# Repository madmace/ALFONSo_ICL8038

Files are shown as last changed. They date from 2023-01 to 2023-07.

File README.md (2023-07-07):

# A.L.F.O.N.S.o based on ICL8038

ALFONSo stands for :

<p align="right">
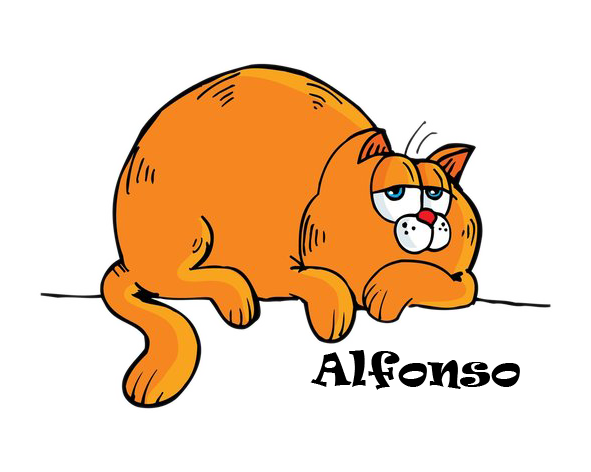
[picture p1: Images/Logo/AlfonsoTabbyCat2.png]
    
</p>

**A**nalog
**L**ow 
**F**requency 
**O**scillator 
**N**olinear 
**S**equencer

In this implementation MK-ICL8038.

- [Meta](#meta)
- [Basics](Basics.md)
- [Power Supply](Power.md)
- [ICs used in VCO & Mixer](ICs.md)
- [Frequency Counter](Frequency.md)
- [Early implementation](#early-implementation)
- [Development pictures](Images.md)
- [Current wiring diagram](https://github.com/madmace/ALFONSo_ICL8038/blob/main/Proteus/Alfonso_ICL8038.PDF)
- [Upcoming implementations](#upcoming-implementations)

## Meta

Scope:

- The project from my passion of analog synthesizers and the love of the patterns, rhythms and mats that colored the majority of the 70s and 80s classics. In particular the analog sequencers and LFOs.
- The use of analog IC monolith signal generators operated in BF in the 1Hz band up to 25KHz. Can be used as VCO/LFO. This first research *intentionally* uses the older, now obsolete, but *well known* **Intersil ICL8038**.
- The digital control interface via USB is based on an *old and well-known* Microchip **18-series** microcontroller. The **PIC18F4550** is a widely used mC and there is a large amount of example code and tutorials available on the web.
  However, I personally always suggest having its datasheet handy and dedicating the time to understand its correct functioning.
- Alfonso uses the USB 2.0 peripheral contained in the 18F4550 microcontroller. The firmware exposes the USB port as a CDC (USB communications device class). This allows it to be recognized by all OSes as an RS232 serial port.
  I originally intended to use the USB port as a Human Interface Device (HID) but due to its limitations I decided to implement it as a CDC and build a proprietary protocol on it.

## Early implementation

This first implementation is oriented to develop and test all the HW functionalities of the VCOs/LFOs and the core SW libraries for their command.
For this, a first mixer with the basic functions was developed.

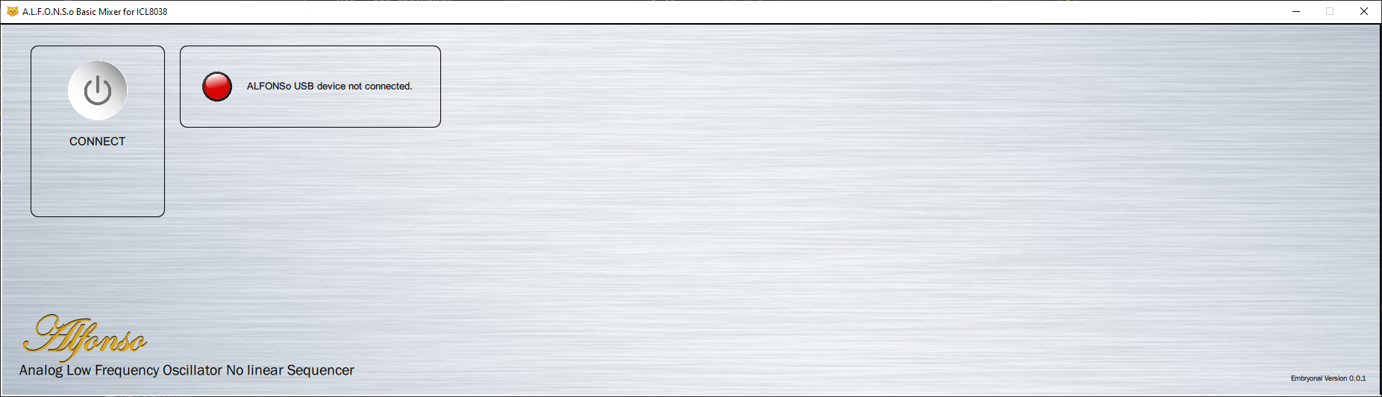
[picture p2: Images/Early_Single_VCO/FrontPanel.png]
Front Panel

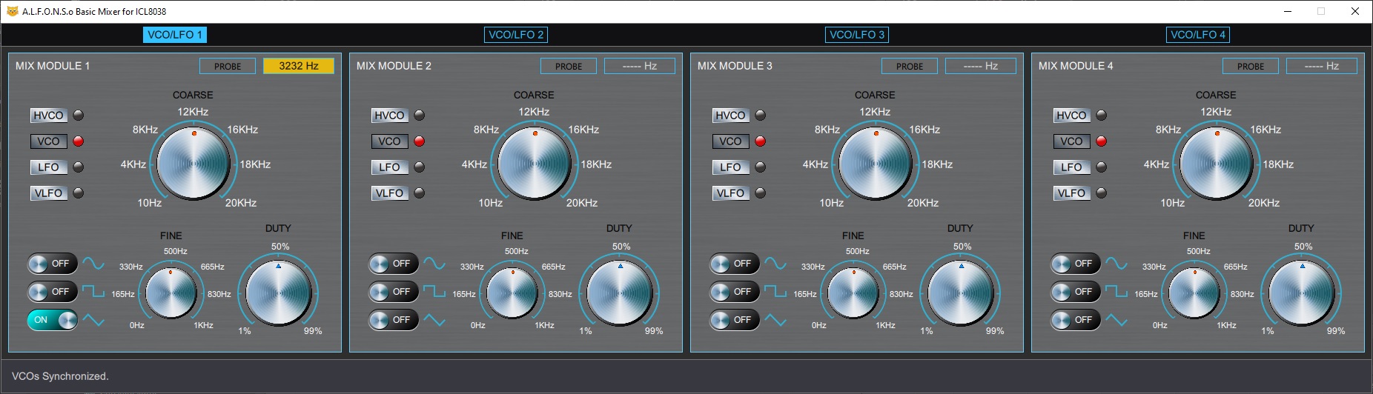
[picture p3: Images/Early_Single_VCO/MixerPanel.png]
Mixer Panel


Both the control logic section and the analog section with the VCO and the mixers are still being prototyped via breadboard.
Once the functionality is stabilized, I will create a welded version for better signal quality. Obviously the air links are not optimal.
    
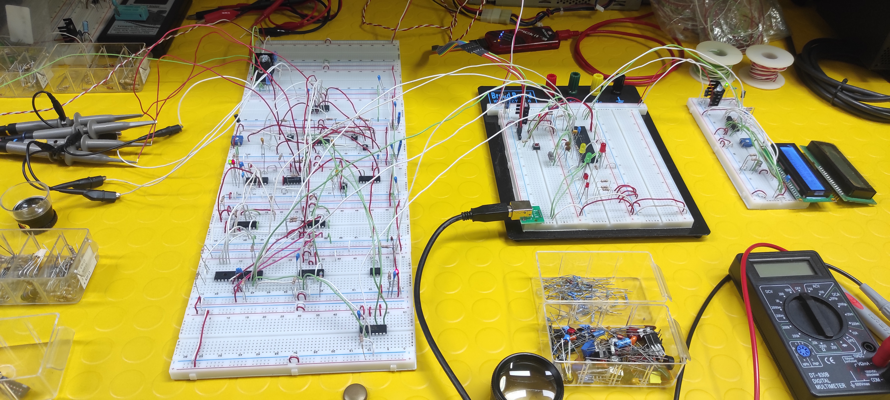
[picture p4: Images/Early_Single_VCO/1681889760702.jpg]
AlfonsoProto


## Upcoming implementations

- It is my intention, once the project based on the **Intersil ICL8038** is completed and stabilized, to re-adapt it for use with the **EXAR XR-2206** Monolithic Function Generator.
  IC is more modern and seems to compensate for certain problems of the *ICL8038*. It is also still supported and in production.
- The impact on the Firmware of the transition of the current mC **PIC18F4450** towards the new version, currently supported by the *MCC of MPLABX*, mC **PIC18F45K50** is minimal.
  So as soon as the current version stabilizes, I'll switch to this mC.

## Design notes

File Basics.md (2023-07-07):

---
title: Basics
layout: template
filename: Basics.md
--- 

## Basics

The **ICL8038** waveform generator is a monolithic integrated circuit capable of producing high accuracy sine, square, triangular, sawtooth and pulse waveforms.
The frequency (or repetition rate) can be selected externally from 0.001Hz to more than 300kHz.
In used configuration, the frequency has been fixed in the audio frequency range 1Hz to 20KHz.
As a quick description of how waveforms are produced, the integrators via comparators create the primary triangle which is then flip-flopped to obtain the square and a smoothing network based on multiple transistors stages to obtain the sine.
The sweep is modulated via a DC voltage. The relative frequency range depends on the capacitor applied.

Four different meshes with different values are needed to get good linearity.
This especially applies to operation as an LFO.
Four different selectable operating modes have been selected.

***Frequency ranges***

The frequency ranges are still raw and are related to the values of the capacitors used in the VCO applied to pin 10 of the ICL8038.

- **HVCO** (*1.6KHz to 26KHz used capacity 2.2uF*)
- **VCO** (*238Hz to 4.1KHz used capacity 220nF*)
- **LFO** (*11Hz to 194Hz used capacity 22nF*)
- **VLFO** (*3Hz to 67Hz used capacity 2nF*)

The selection of the frequency range is set using the micro via the I/O Expander **MCP23S17** and the Quad Bilateral Switch **CD4066B**.
Only one of the four bilateral switches is active defining the frequency range.

***Notice !***
The capacitor values and frequency range are still being refined, so the correct values will only be released upon completion of the design of the VCOs module.

[Return to index.](README.md)

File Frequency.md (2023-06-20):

## Frequency Counter

The purpose of this module is to communicate the current frequencies of the VCOs to the PC.

***Implementation via CCP module (Capture / Compare/ PWM) as "Initial choice"***

My intention was to use the Capture mode of the two available CCPs,
in particular the CCP2 combined with the Timer3 to calculate the frequency of the 5V/0 square conditioned signal made compatible with the digital input.

I didn't want to use other external components, thus subtracting other GPIOs from the uC.<BR>
My choice was to directly use the FOsc of 48Mhz / TOsc of 12Mhz on the Timer3.

The four operating ranges of the VCOs would have been managed with different samplings of the CCP.

- **HVCO** Capture mode: every 16th rising edge
- **VCO** Capture mode: every 4th rising edge
- **LFO** Capture mode: every rising edge
- **VLFO** Capture mode: every rising edge

With the 16-bit Timer3 and associated to the uC clock oscillator :

12Mhz/64K = 183 Timer3 Overflows per second.
With : 1/183 = 5.4644~ ms for each Overflow.

In the case of management with a single Overflow, this is the maximum time available to the CCP2.<BR>
So the minimum frequencies with respect to the three sampling ratios :

- 1:1 every rising edge 183 Hz
- 1:4 every 4th rising edge 732 Hz
- 1:16 every 16th rising edge 2.928 KHz

In VLFO mode the minimum frequency is ~3Hz, so we're not there.

The problem is Timer3 is the reference frequency which is very high.

***Reference 16bit Timer with managed Overflows***

To solve the problem I thought if it was possible to use a management with the managed Overflow of the same Timer3.

- With double Overflow management, the maximum period would be : 10.9289 ms for a minimum frequency of 91.5 Hz
- With triple Overflow management, the maximum period would be : 16.3932 ms for a minimum frequency of 61 Hz
- With a management of ten Overflows the maximum period would be : 54.644 ms for a minimum frequency of 18.3 Hz

This added to the fact that the Timer3 has the possibility to be managed via Prescaler 1:2, 1:4, 1:8 I could have achieved the goal,
but at the cost of a high computational complexity in the uC and a high imprecision given by the decimals.

So I decided to abandon the solution via CCP.

***Timer1 with external quartz 32.768KHz as RTC***

The Timer1 of the micro has the possibility of advancing with the system clock but also with an external quartz.
In this case I used the classic 32.768Khz RTC quartz. This technique is extensively described in the PIC18F4550 datasheet on page 131, paragraph 12.3.

By setting the Timer1 register with an initial prescaler of 0x8000 (32768) we obtain that each Timer1 overflow corresponds exactly to one second.
This is why it is called RTC crystal.

In addition to Timer1, Timer0 configured at 8 bit is used to take the clock from pin T0CKI as input.
This input clock is actually the appropriate 0/5V square rectified output for the VCO's frequency counter.

The overflows of Timer0 in the period of one second are counted, then in the overflow of Timer1.

The final frequency will simply be:

- FreqHz = Number of Overflows Timer0 * 256 + Timer0;

This is because the calculation is done at the timer1 overflow which is one second.

[Return to index.](README.md)

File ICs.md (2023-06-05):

## ICs used in VCO & Mixer

**ICL8038** Precision Waveform Generator/Voltage Controlled Oscillator<BR>
An problem with this generators is strong distortion on sine wave output pin 2, so most of the solutions based on this chip has a limited frequency.
Another is that the square wave output from pin 9 is an open collector that needs to be pulled up to the power supply. In some way the quality of other waveforms is dependent on the load on this pin. I excluded the 15M potentiometer indicated in the datasheet on page 7, squeezes the top of the upper half of the signal.
As mentioned, square output pin 9 with open collector, normally would never be able to give a good square wave at these frequencies. Rising edge depends only on the pull-up resistor and its growing very slowly. If we give too strong pull-up resistor, in turn, the trailing edge will be weak because the internal transistor is too heavily loaded. 
Here, I fixed the square wave with a comparator so that the slope is pretty steep, steep as applied comparator can give. Shown in the schematic LM339 has 1.3μs response time but it would be good to use even faster model of comparator.
The amplitude of the signal, unfortunately, is not the same for each function, tests have shown that trying to match it with the usual R/R signal dividers will give very distorted waveforms as rounded square and triangle, so i resigned from such divisors.

Sine output on pin 2 as ratio 0.22~ * Vcc<BR>
Triangle output on pin 3 as ratio 0.33~ * Vcc<BR>
Square output on pin 9 as ratio 0.9~ * Vcc<BR>

This however was not a problem since I use the Quad OpAmps TL084 as a mixer anyway. What I cannot avoid at this point is the use of trimmers for signal calibration at 2Vpp.

The physical potentiometers for frequency sweep and duty cycle are respectfully replaced, by the 10KΩ MCP42010 and the 5KΩ MCP4251.

For each VCO both potentiometers of the MCP42010 are used. So there's a MCP42010 for VCO. One is used as the main one and the other is in series for fine tuning.
Only a single one MCP4251 potentiometer for duty is used. Half for VCO.

***Frequency Modulation and Sweeping***

The frequency of the waveform generator is a direct function of the DC voltage at Terminal 8 (measured from V+). By altering this voltage, frequency modulation is performed. For small deviations (e.g. ±10%) the modulating signal can be applied directly to pin 8, merely providing DC decoupling with a capacitor.
An external resistor between pins 7 and 8 is not necessary, but it can be used to increase input impedance from about 8kΩ (pins 7 and 8 connected together), to about (R + 8kΩ).
For larger FM deviations or for frequency sweeping, the modulating signal is applied between the positive supply voltage and pin 8.

The potential on Pin 8 may be swept down from V+ by (1/3 VSUPPLY - 2V). Then for ALFONSo from +5V (Low Freq) to +3.33V (High Freq).

**TL084** High-speed JFET input, quad operational amplifiers<BR>
The TL084 is high speed J–FET input quad operational amplifiers. The devices feature high slew rates, low input bias and offset currents, and low offset voltage temperature coefficient.
The TL084 is used to make the harmonics mixer. For each harmonic there is the relative gain adjustment trimmer which allows it to be brought into line with 2vpp.

**LM339** Quad Comparators<BR>
This quad comparator is used extensively to make CD4066B control lines compatible. The CD4066Bs are used to switch the frequency range, to enable individual harmonics and enable the singles VCO.
The CD4066 must have a dual power supply to fully support the signals produced, and in this mode enabling and disabling of the bilateral switches is done with the +5V/-5V control signals.
Then the +5V/0V MCP23S17 I/O Expander outputs are converted to dual levels using the Quad comparators provided by the LM339.
Currently each VCO needs 8 control GPIOs. For a total of two LM339 per VCO dedicated to this purpose.
The LM339 is also used to purify the square wave output which is suboptimal due to the value of the pull-up resistor. In this case one is used for VCO.

**LM393** Dual Comparators<BR>
The LM393 is a dual comparator used primarily to produce a +5V/0 signal, derived from the square wave, compatible with the a generic input of the controller.
This allows the controller to calculate the current frequency of the selected VCO.

**CD4066B** CMOS Quad Bilateral Switch<BR>
The CD4066B is a quad bilateral switch intended for the transmission or multiplexing of analog or digital signals.
The CD4066B consists of four bilateral switches, each with independent controls. Both the p and the n devices in a given switch are biased on or off simultaneously by the control signal. The well of the n-channel device on each switch is tied to either the input (when the switch is on) or to VSS (when the switch 
is off). This configuration eliminates the variation of the switch-transistor threshold voltage with input signal and, thus, keeps the on-state resistance low over the full operating-signal range.

***SPI Devices***

The PIC18F4550 has only one MSSP *(Master Synchronous Serial Port)*. While it can be dynamically reset, the open-drain nature of the I2C *(Inter Integrated Circuit)* protocol makes it incompatible with SPI (Serial Peripheral Interface).
So I chose to use only SPI peripherals even with the expenditure of lines for the various CSs *(Chip Select)*.

SPI ICs used :

**MCP23S08** High-speed SPI 8-Bit I/O Expander from Microchip<BR>
A very convenient prerogative of this series of SPI I/O Expanders is that it has the possibility of setting additional hardware addresses which allow you to select the peripheral with the same CS line.
In the case of the MCP23S08 it has two address pins wired for a total of four I/O expanders per CS.
In the project it is used to drive via SPI the Hitachi HD44780-based LCD in four bit mode, the related handshake and internal LED lighting signals.
In the microcode a specific library has been developed for the coupling of the MCP23S08 and the HD44780.

**MCP23S17** High-speed SPI 16-Bit I/O Expander from Microchip<BR>
Like its minor brother MCP23S08, the MCP23S17 has the ability to set hardware addresses switching from previous two to three addresses for eight devices on the same CS line.
The MCP23S17 is used to drive the numerous analog bilateral switchs found in mixers. There is one for each two VCO module.
    
**MCP42010** Dual Digital Potentiometer SPI
The IC is a double potentiometer with 256 taps 8-bit for each potentiometer. The MCP42XXX series is with the internal register is volatile. So it doesn't keep the last setting. At the moment it is the software that imposes all the default levels on connection. The permanent model is also available in case of future considerations.
The MCP42XXX series is available with the values for 10 kΩ, 50 kΩ and 100 kΩ. There is a nominal wiper resistance of 52Ω for the 10 kΩ version, 125Ω for the 50 kΩ and 100 kΩ versions. The channel-to-channel matching variation is less than 1%. The resistance between the wiper and either of the resistor endpoints varies linearly according to the value stored in the data register. At power-up or upon habilitation the RS, all data registers will automatically be loaded with the mid-scale value (80h). The Shutdown pin SHDN, if enabled, leaves the A terminal is opened and the B and W terminals are connected for all potentiometers.
A feature of this SPI IC is the presence of SO output pin, multiple devices can be daisy-chained together.
    
**MCP4251**
The IC is a double potentiometer with 257 taps 8-bit for each potentiometer. The MCP4251 also has volatile internal register loaded with the mid-scale value (80h).
It has a nominal wiper resistance of 75Ω typical for all available values 5kΩ, 10kΩ, 50kΩ, 100 kΩ.

[Return to index.](README.md)

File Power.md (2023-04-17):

## Power supply

***Initial choice***

As an initial choice I thought that the dual power supply for the linear/analog section should be greater than the positive voltage used by the digital section.
I thought this thing would bring me more room for work. 
For this the whole VCO section was powered with a dual voltage -8V/+8V and digital control section which includes the mC and all the SPIs is instead powered with +5V/0V.

However, this has brought me problems with digital potentiometers that cannot withstand voltages higher than the supply voltage on the R2R ladder.

As visible in the previous version of the diagram, a level voltage shifter based on the LM358 has been used, to bring the variation per divider of the MCP42010 (0 to 5V) to the compatible values for the ICL8038 powered at +8/-8V (3.3V to 8V).
Same problem occurred with the MCP4251 used to manage the duty cycle.
To solve these problems and not further increase the circuit complexity I decided to use the +5/-5V power supply for the VCO section.

***Summing up***

The whole VCO section is powered with a dual voltage -5V/+5V. Swing is then reduced at the final outputs to the standard preamp signal of 2Vpp.
The digital control section which includes the mC and all the SPIs is instead powered with +5V/0V.
An EMC/EMI differential-mode (DM) filter is used on the mains power line and no switching technology is used.

[Return to index.](README.md)

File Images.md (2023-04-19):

## Early Single VCO Proto on breadbaord

AlfonsoProtoBoard
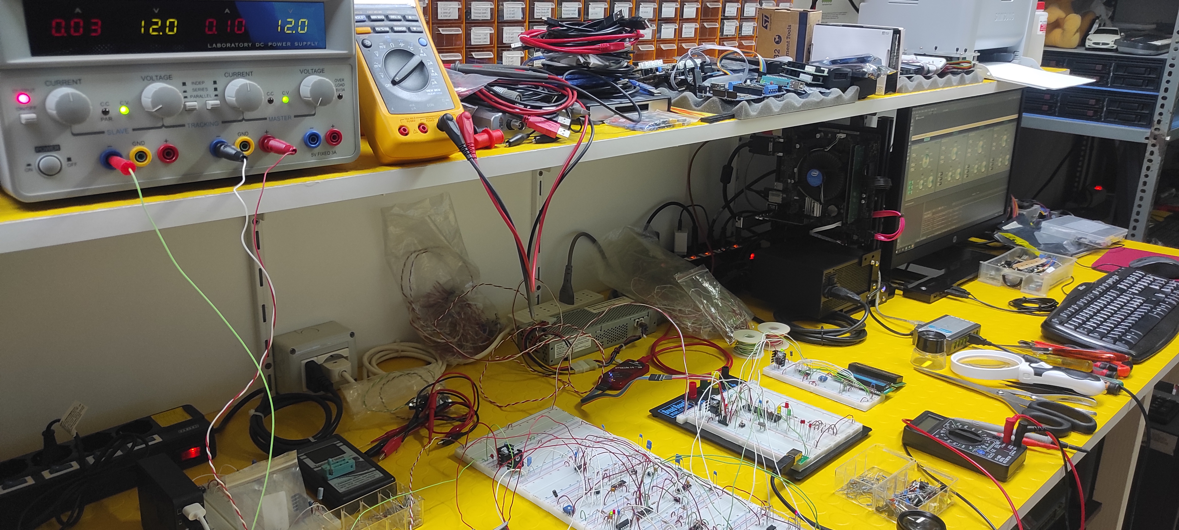
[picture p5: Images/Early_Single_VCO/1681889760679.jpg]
AlfonsoProtoView

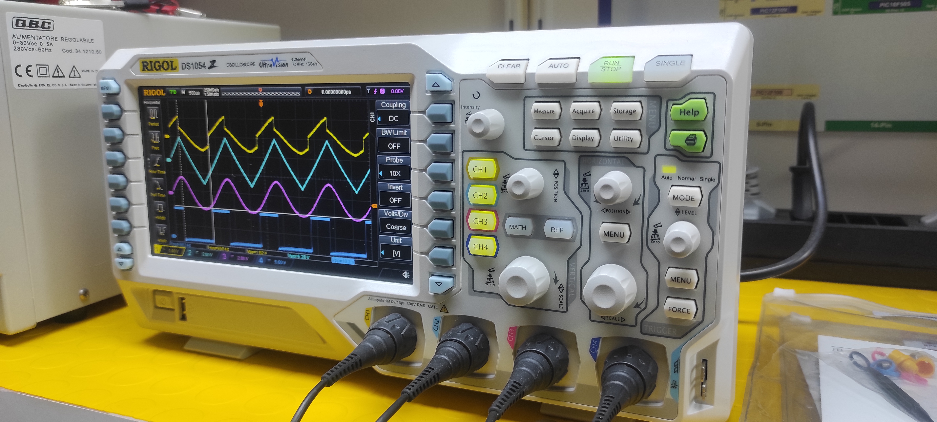
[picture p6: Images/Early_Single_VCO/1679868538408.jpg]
AlfonsoProtoSumWaveVCO

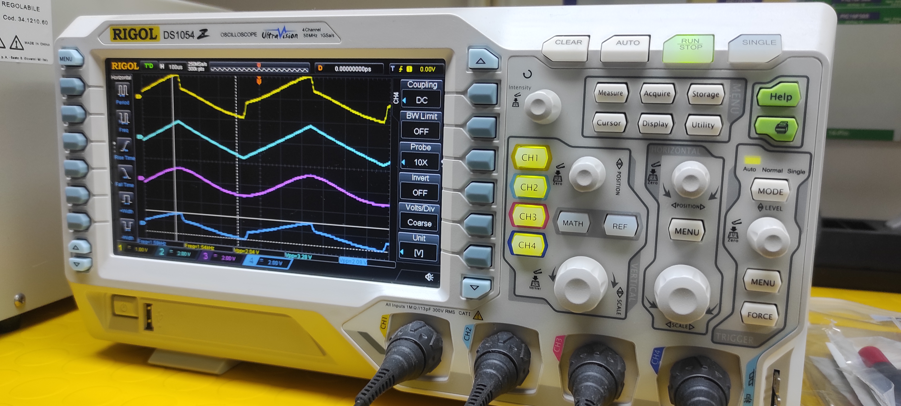
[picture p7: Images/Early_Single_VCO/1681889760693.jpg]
AlfonsoProtoSumWaveLFO

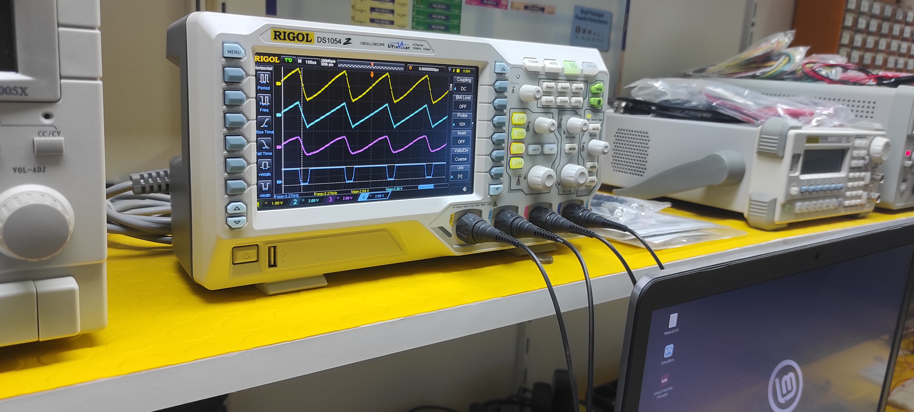
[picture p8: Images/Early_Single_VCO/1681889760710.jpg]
AlfonsoProtoSumWaveDuty


[Return to index.](README.md)

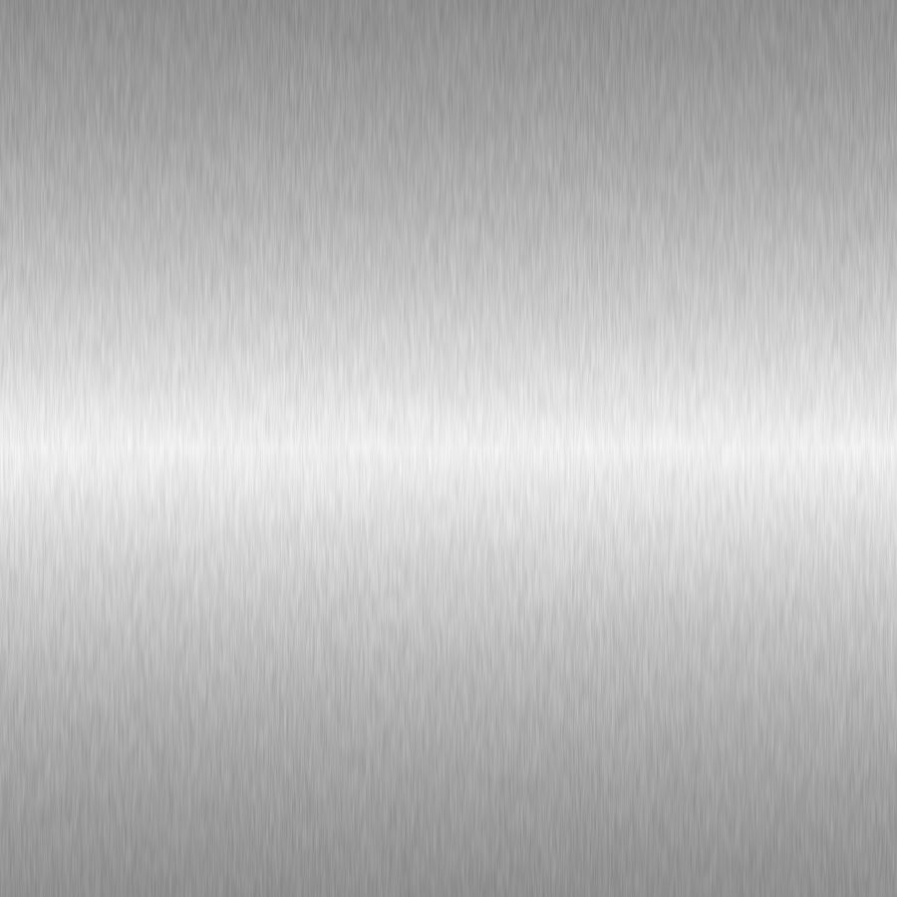
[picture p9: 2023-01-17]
Qt/resources/alum-texture-gray-900x900.jpg

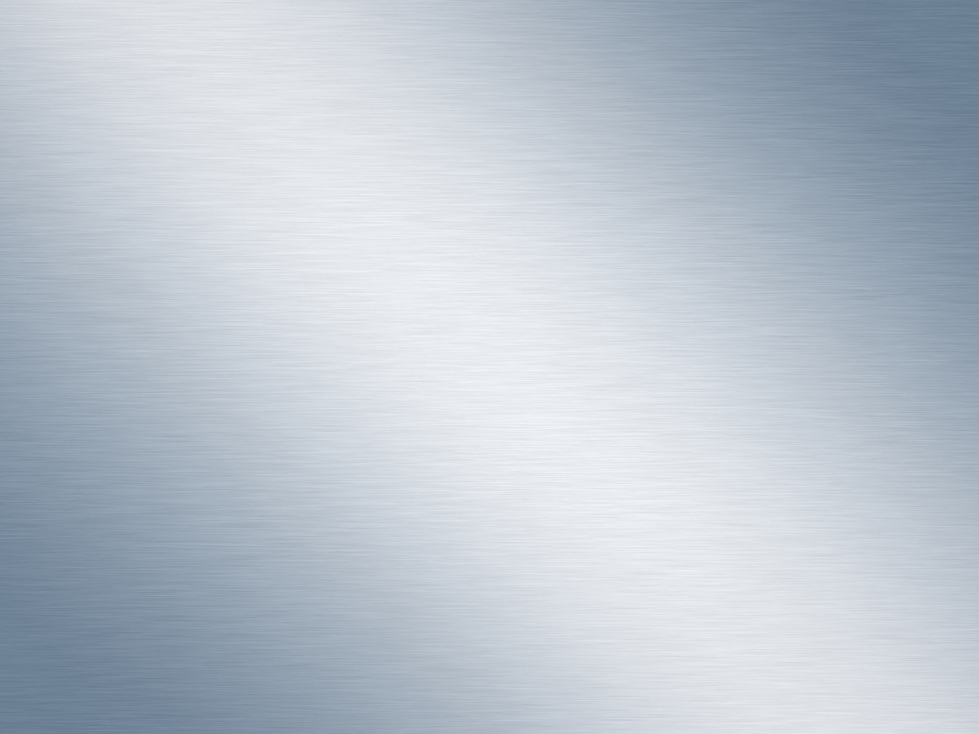
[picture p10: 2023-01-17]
Qt/resources/alum-texture-blue-900x900.jpg

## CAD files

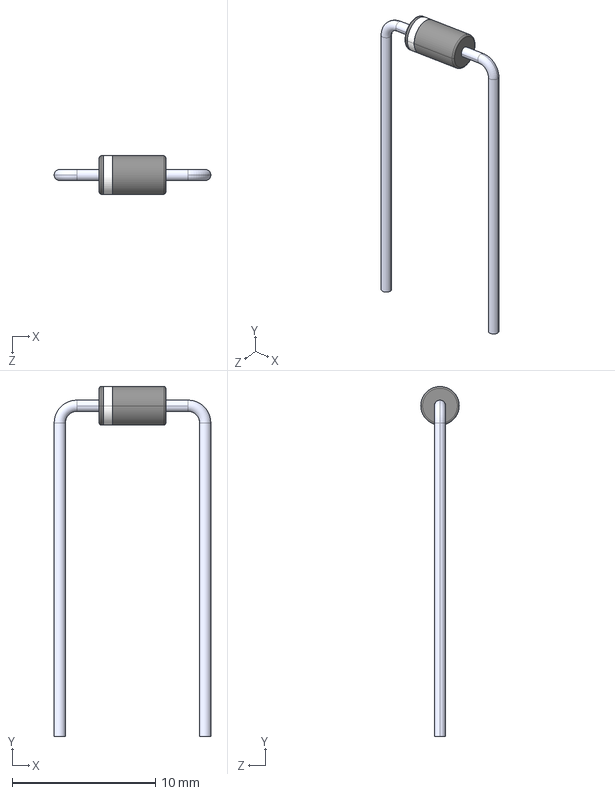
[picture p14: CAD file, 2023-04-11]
Proteus/parts/SMD-DIODE-SCHOTTKY-40V-1A_DO-214AC_.step
10.9 x 24.5 x 2.69 mm

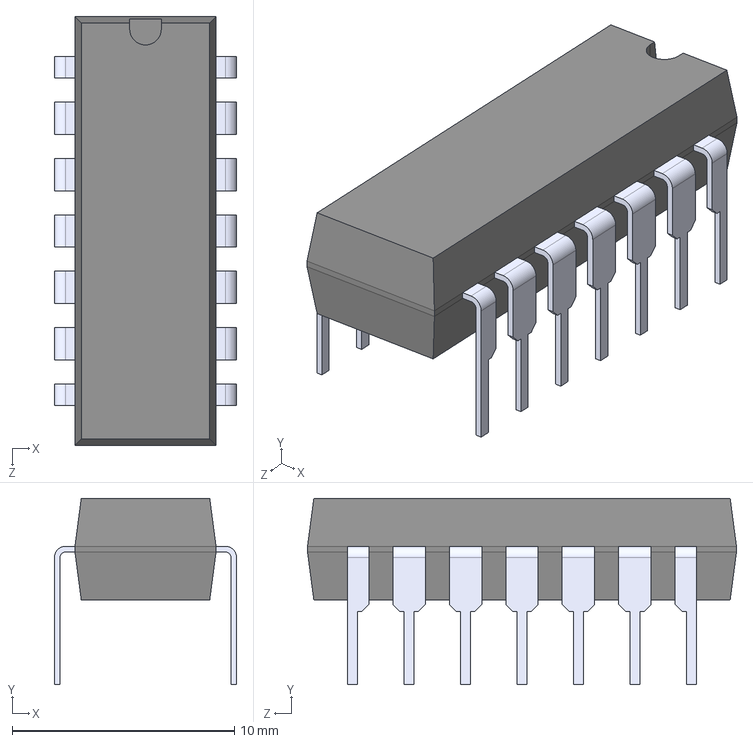
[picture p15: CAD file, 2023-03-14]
Proteus/parts/CD4066BE.step
8.19 x 8.38 x 19.3 mm

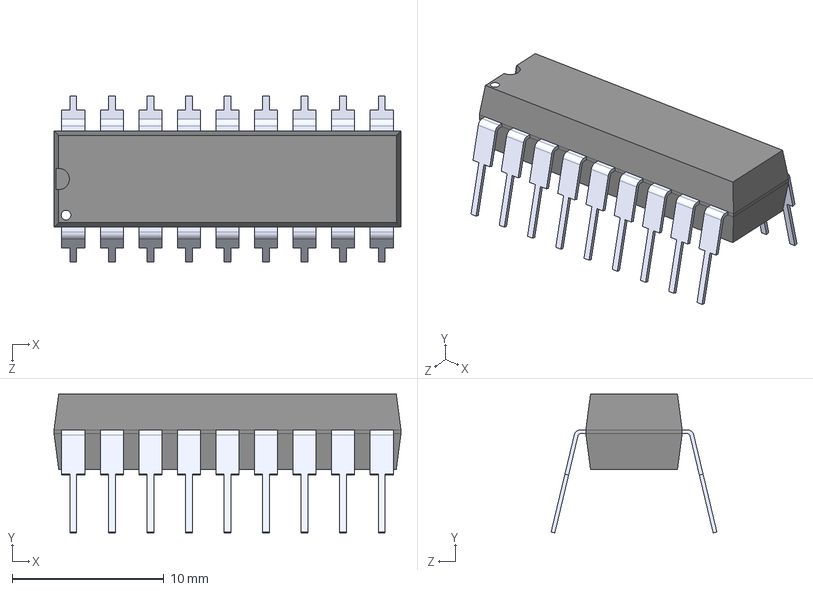
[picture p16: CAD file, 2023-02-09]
Proteus/parts/MCP23S08-E_P.step
22.9 x 9.14 x 10.9 mm

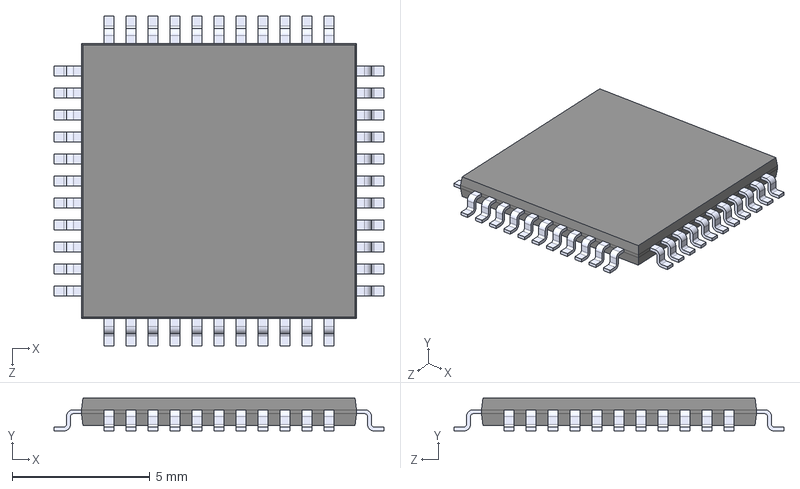
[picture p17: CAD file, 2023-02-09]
Proteus/parts/PIC18F4550-I_P.step
12.0 x 1.20 x 12.0 mm

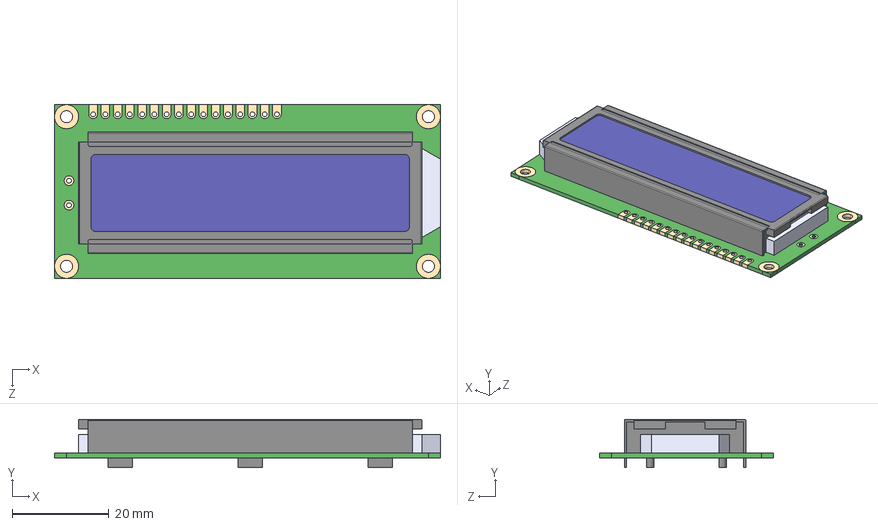
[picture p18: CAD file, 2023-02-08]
Proteus/parts/LCD2X16.step
80.0 x 10.0 x 36.0 mm

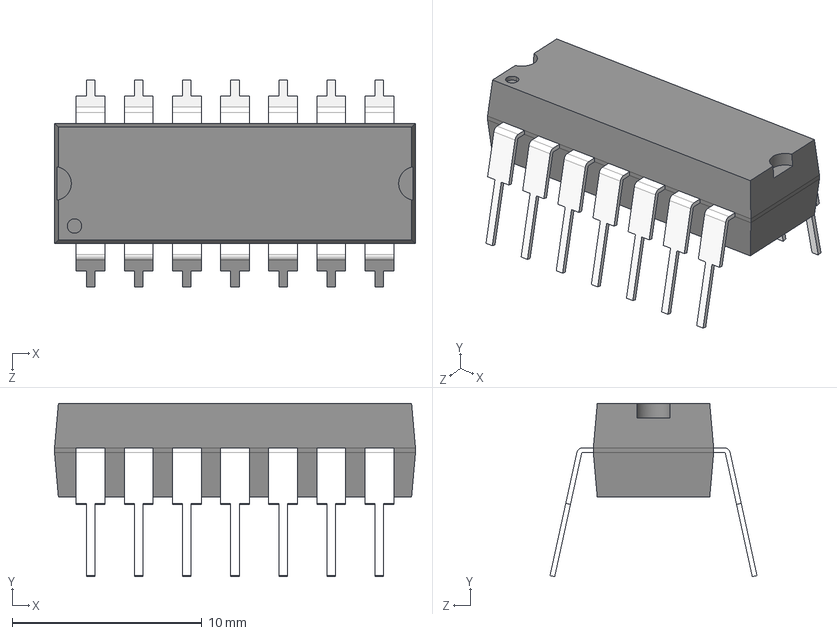
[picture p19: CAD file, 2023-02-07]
Proteus/parts/MCP42010-I_P.step
19.1 x 9.14 x 10.9 mm

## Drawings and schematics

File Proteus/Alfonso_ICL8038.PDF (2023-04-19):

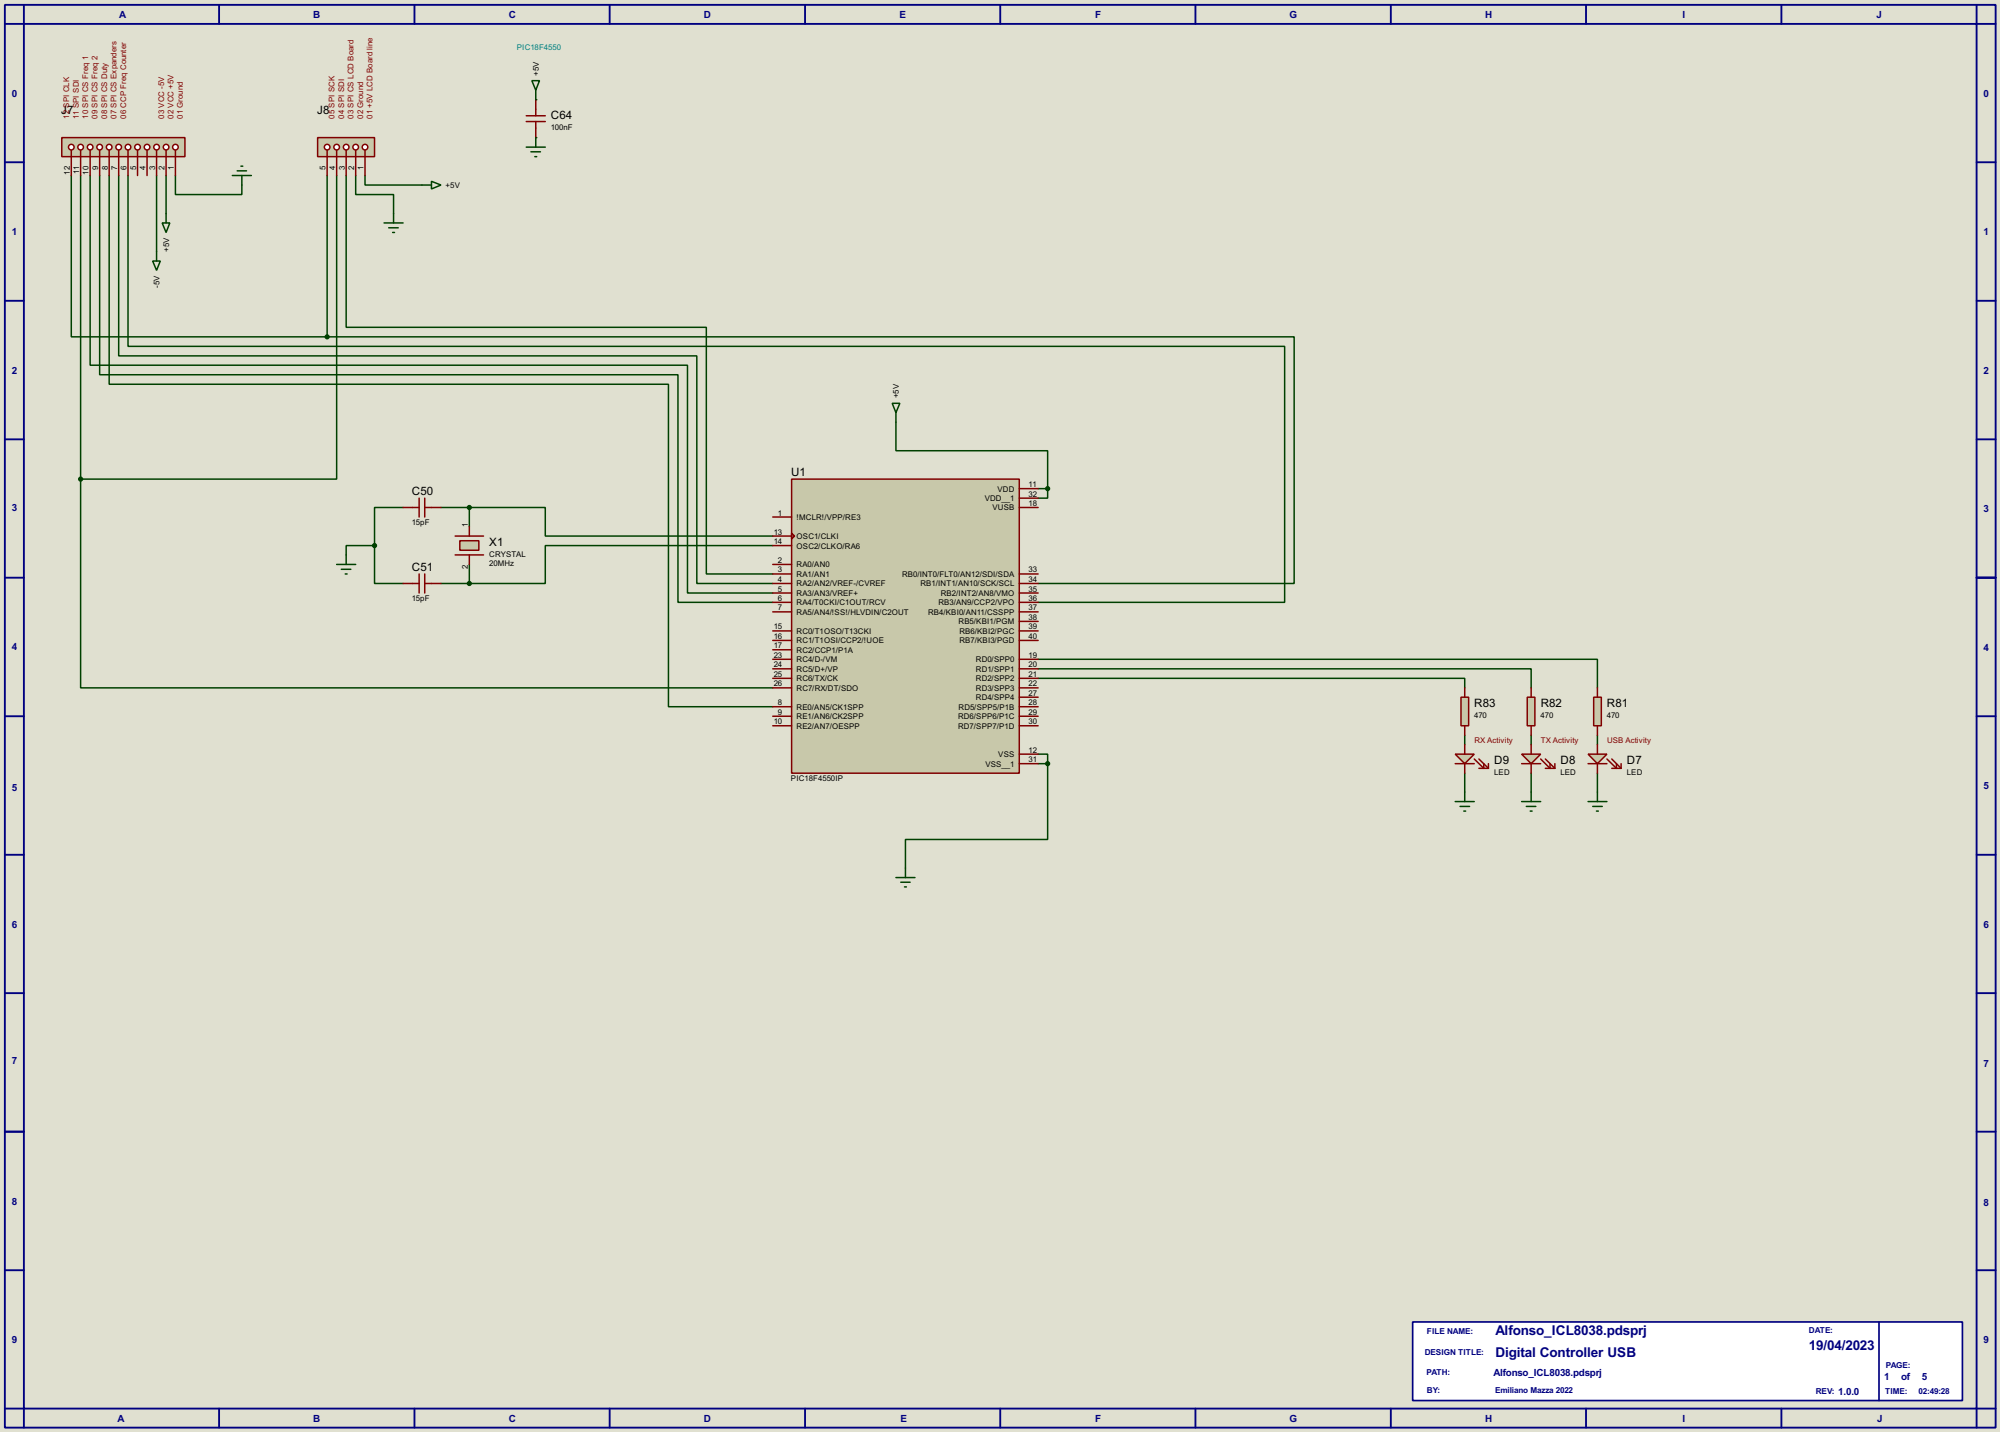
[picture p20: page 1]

08 SPI CS Duty 07 SPI CS Expanders

04 SPI SDI 03 SPI CS LCD Board
J8 05 SPI SCK

11 SPI SDI 10 SPI CS Freq 1

15pF | 5 | | 35 RB3/AN9/CCP2/VPO

RA4/T0CKI/C1OUT/RCV

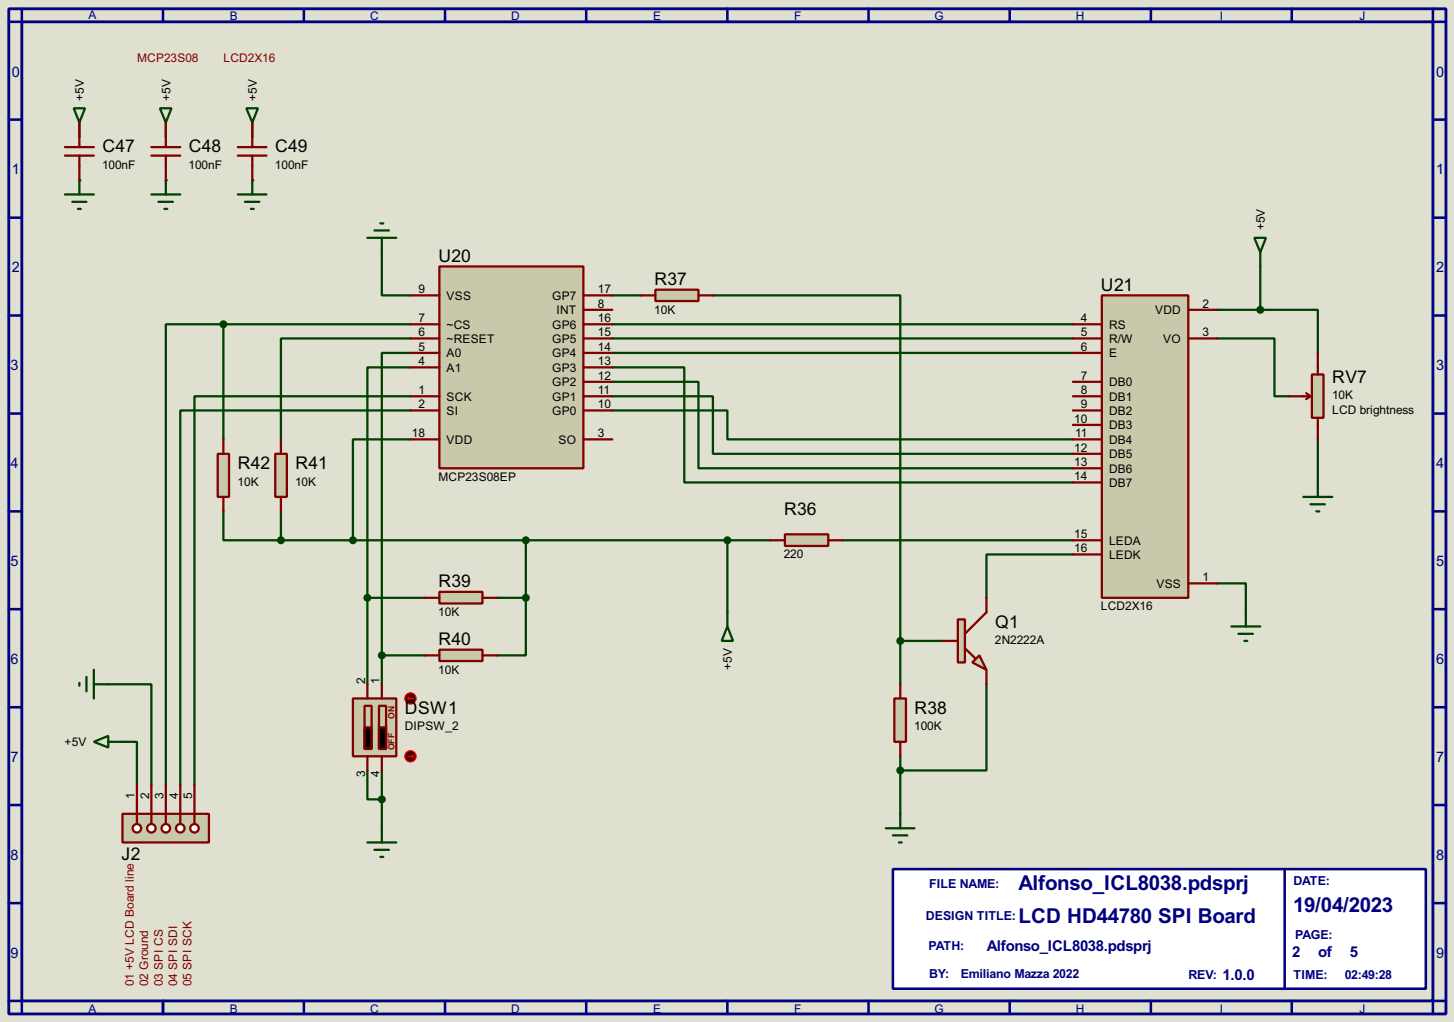
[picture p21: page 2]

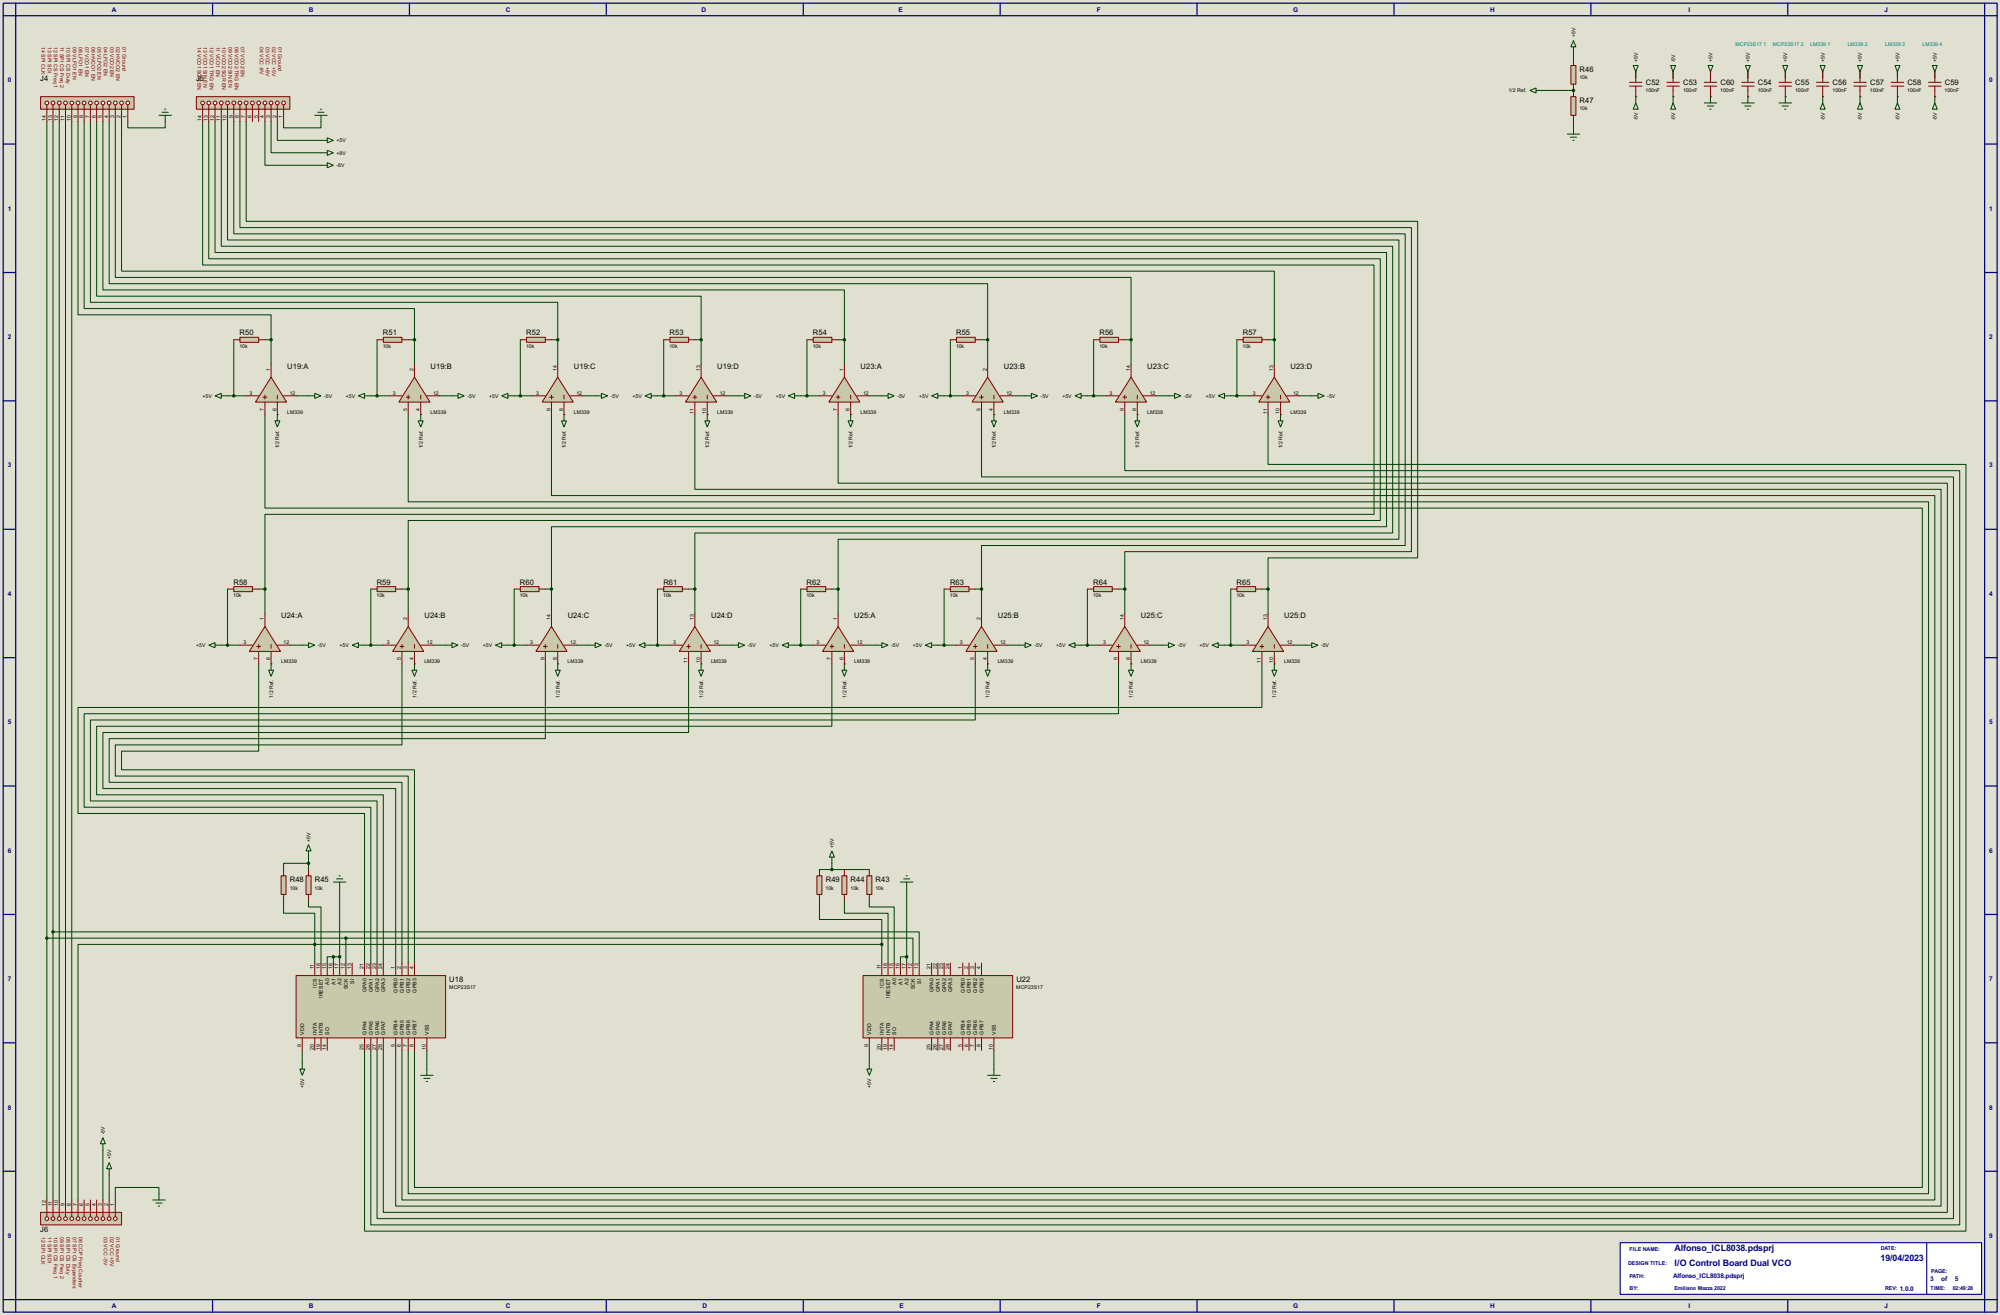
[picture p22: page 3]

13 SPI SDI 12 SPI CS Freq 1

10 SPI CS Duty 09 VLFO1 EN

11 SPI SDI 10 SPI CS Freq 1

08 SPI CS Duty 07 SPI CS Expanders

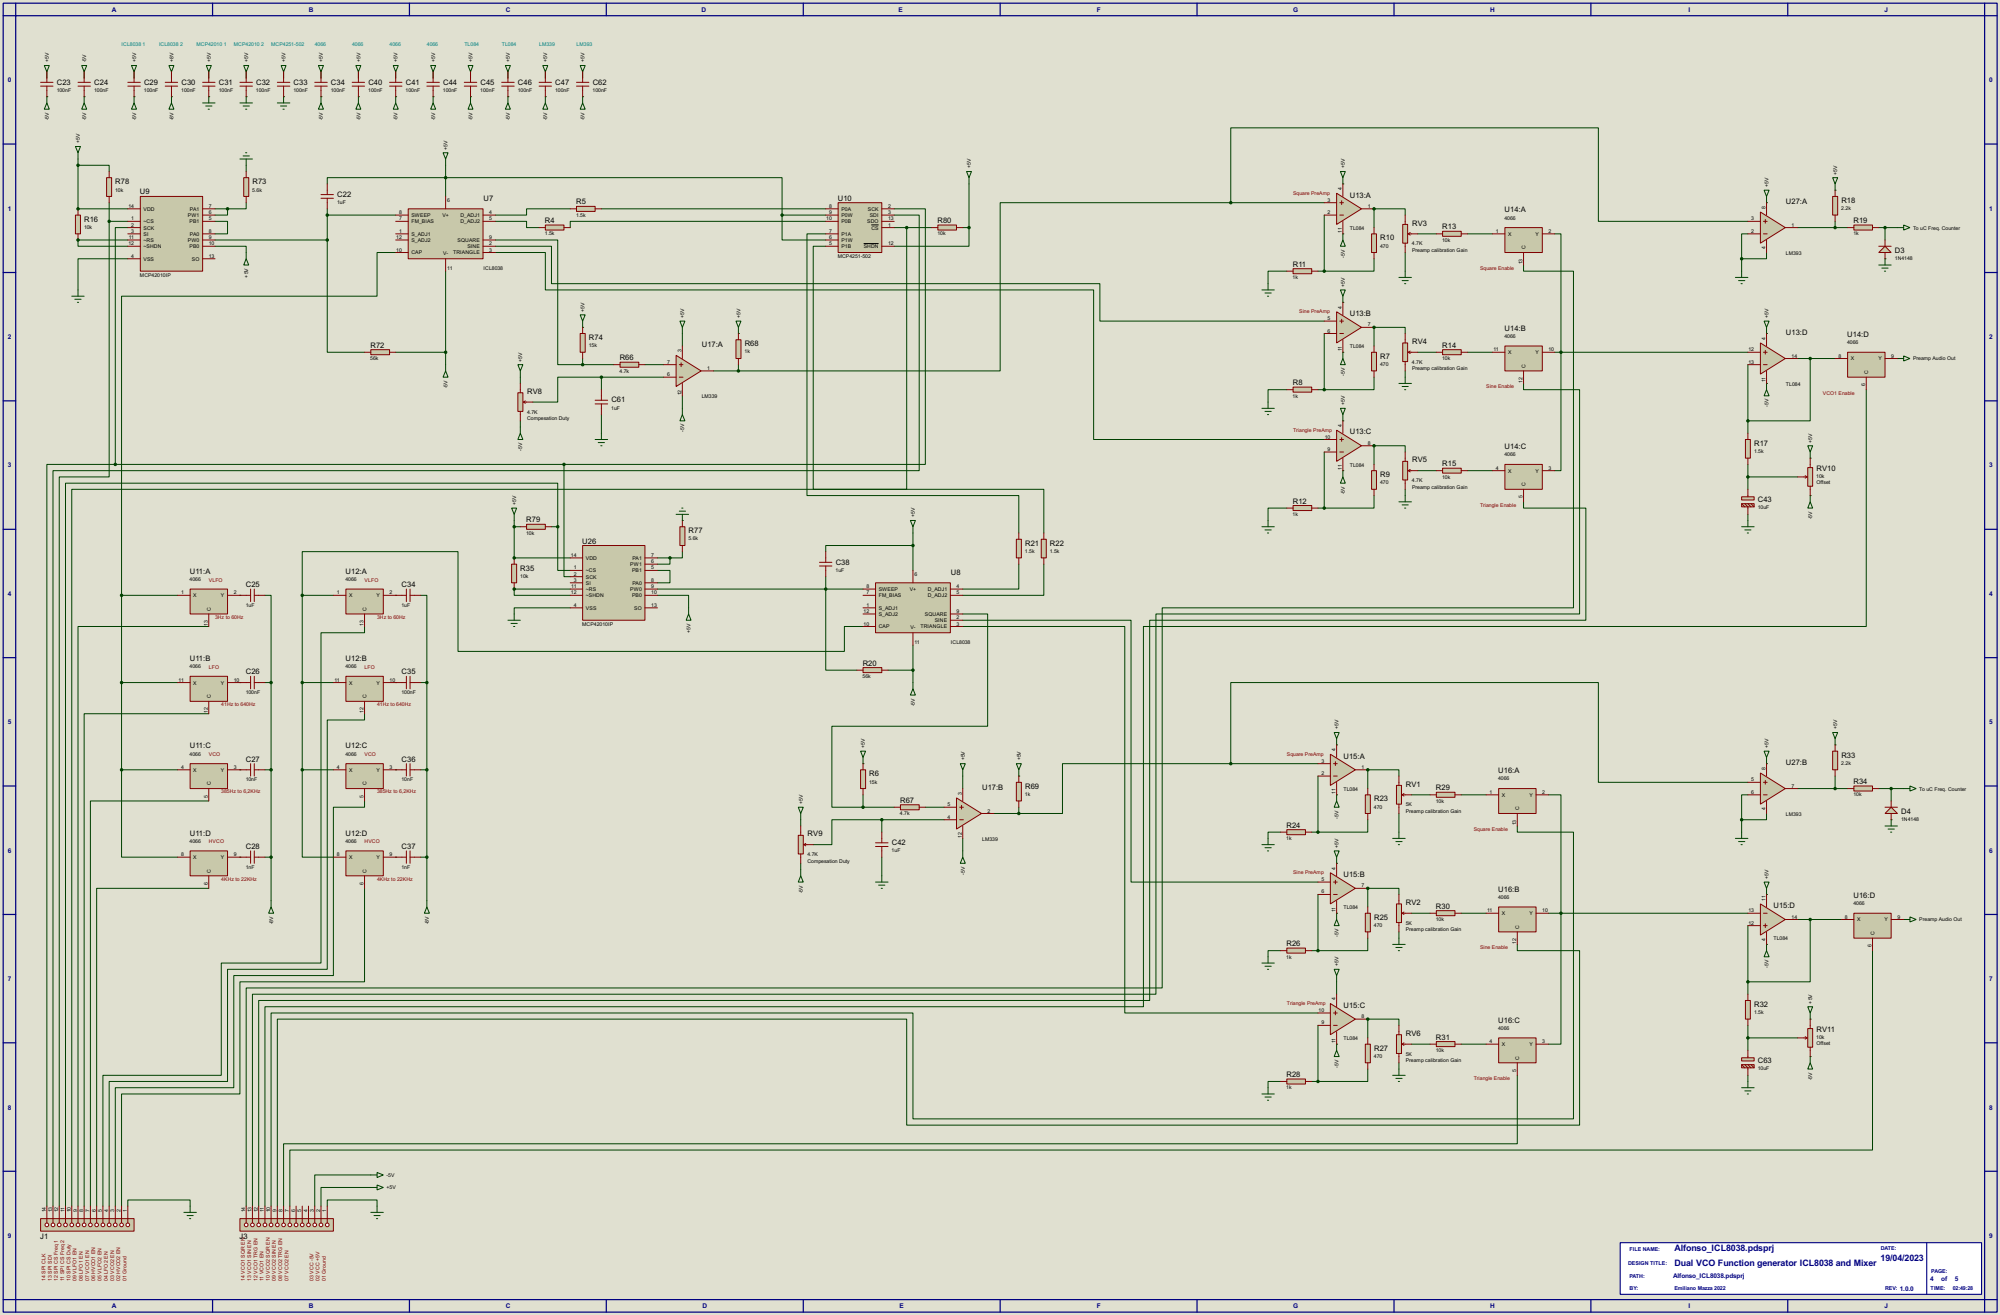
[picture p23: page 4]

8 | P0W P0A | 2 SDI 3 CS

R16 | 1 | PW1 ~CS PB1 | 6 SCK 5 | 8 7 | FM_BIAS | 4 D_ADJ2 5 V+ | 9 10 | P0B SDO | 13

SCK

To uC Freq. Counter

13 SPI SDI 12 SPI CS Freq 1

10 SPI CS Duty 09 VLFO1 EN

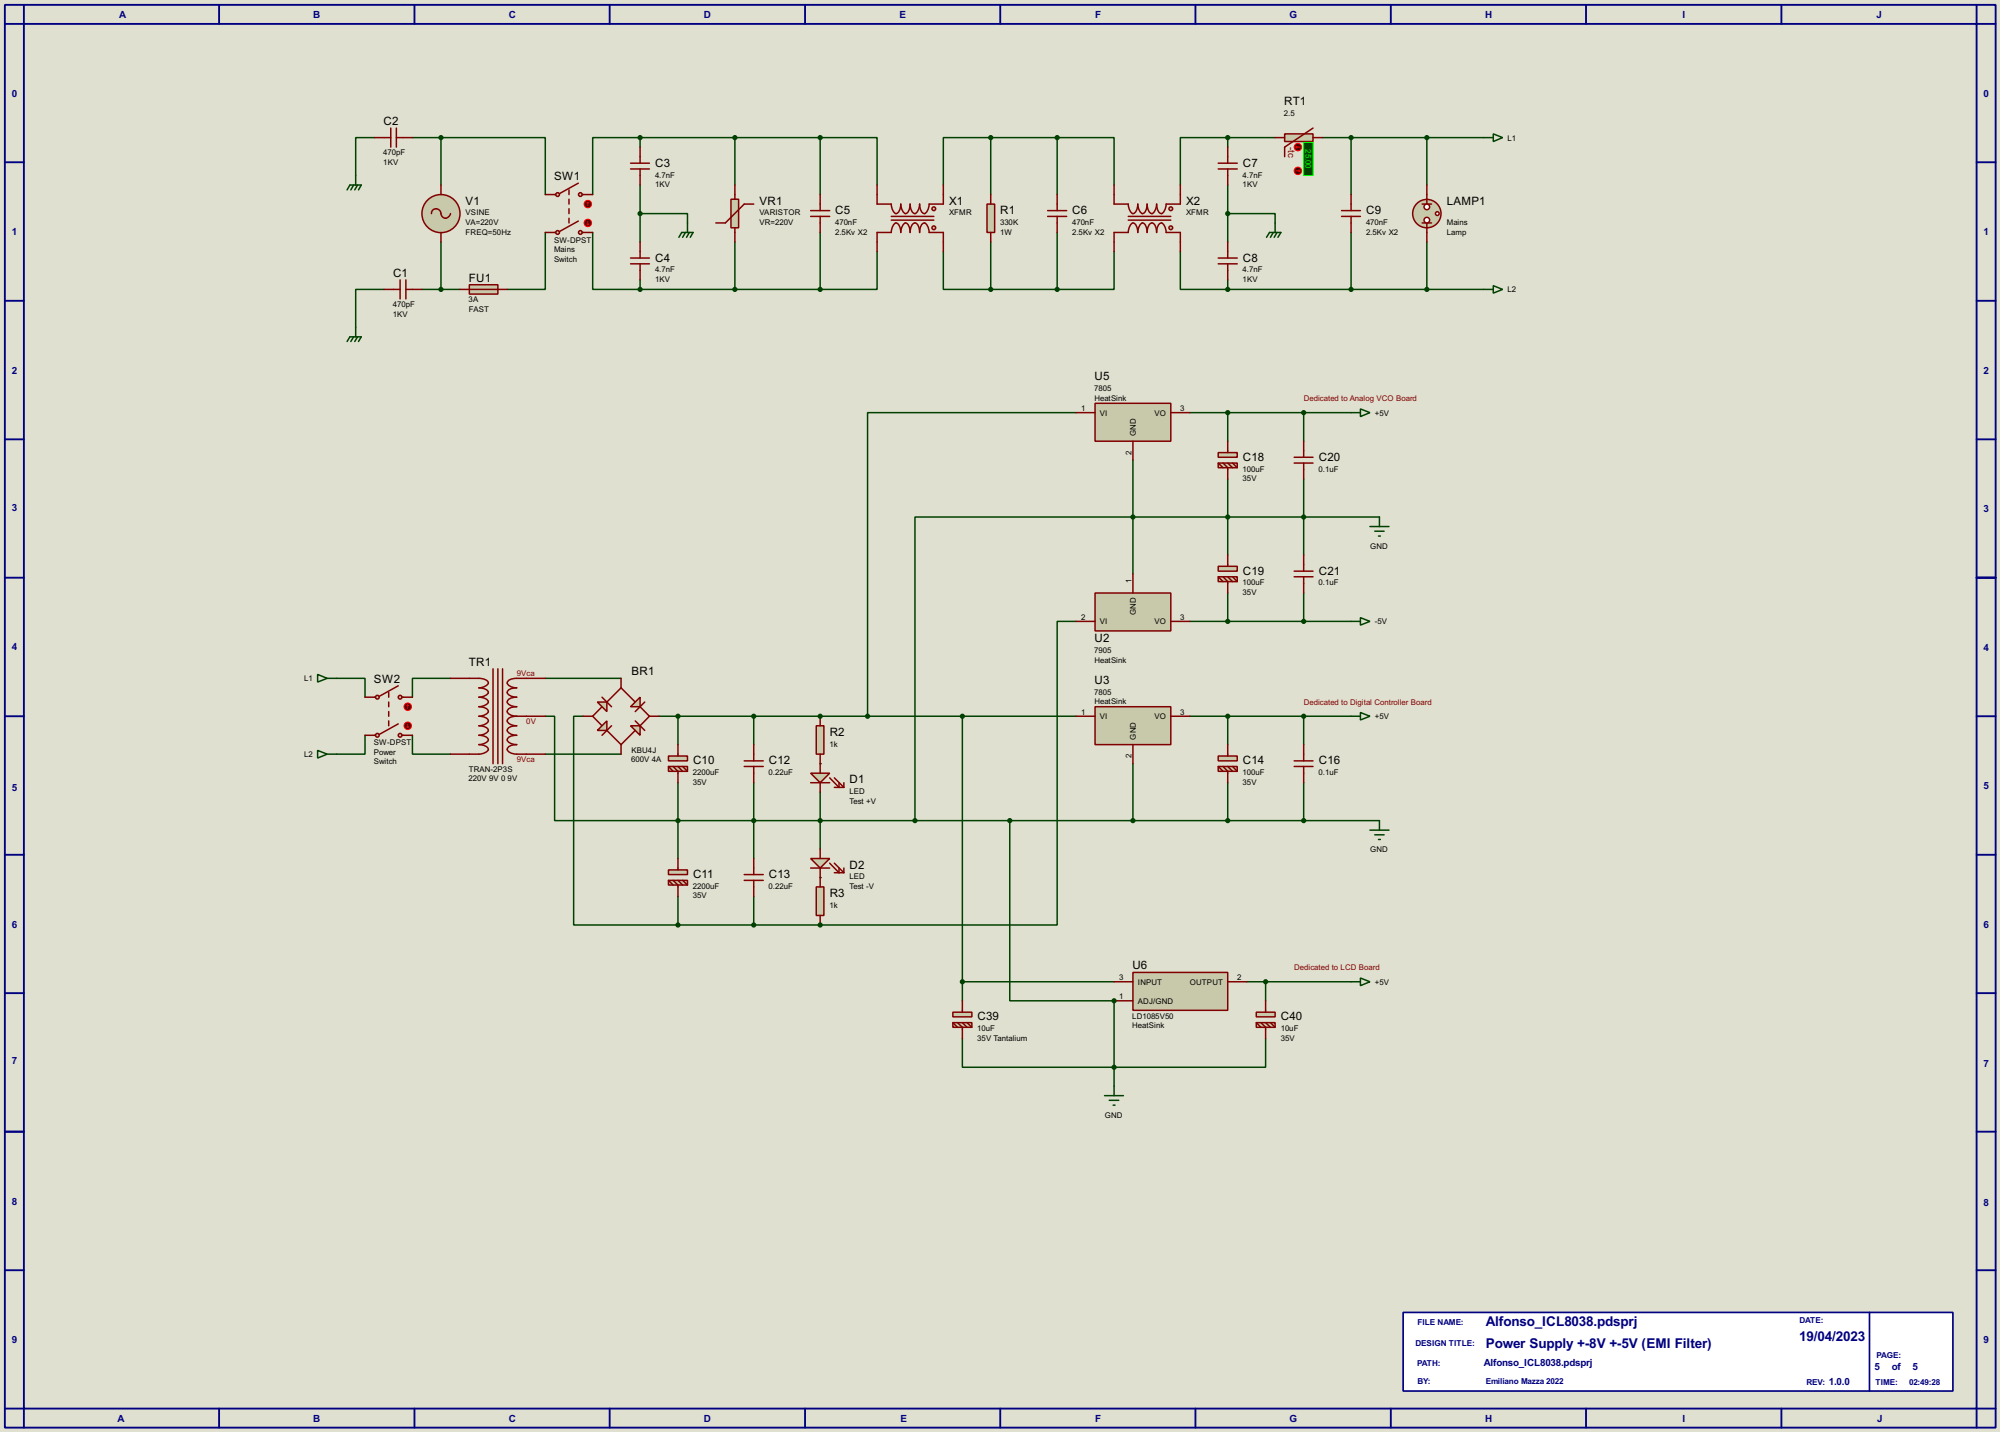
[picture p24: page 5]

SW-DPST Mains Switch

Dedicated to Analog VCO Board

Dedicated to Digital Controller Board

SW-DPST Power Switch

D1 LED Test +V

D2 LED

+5V Dedicated to LCD Board

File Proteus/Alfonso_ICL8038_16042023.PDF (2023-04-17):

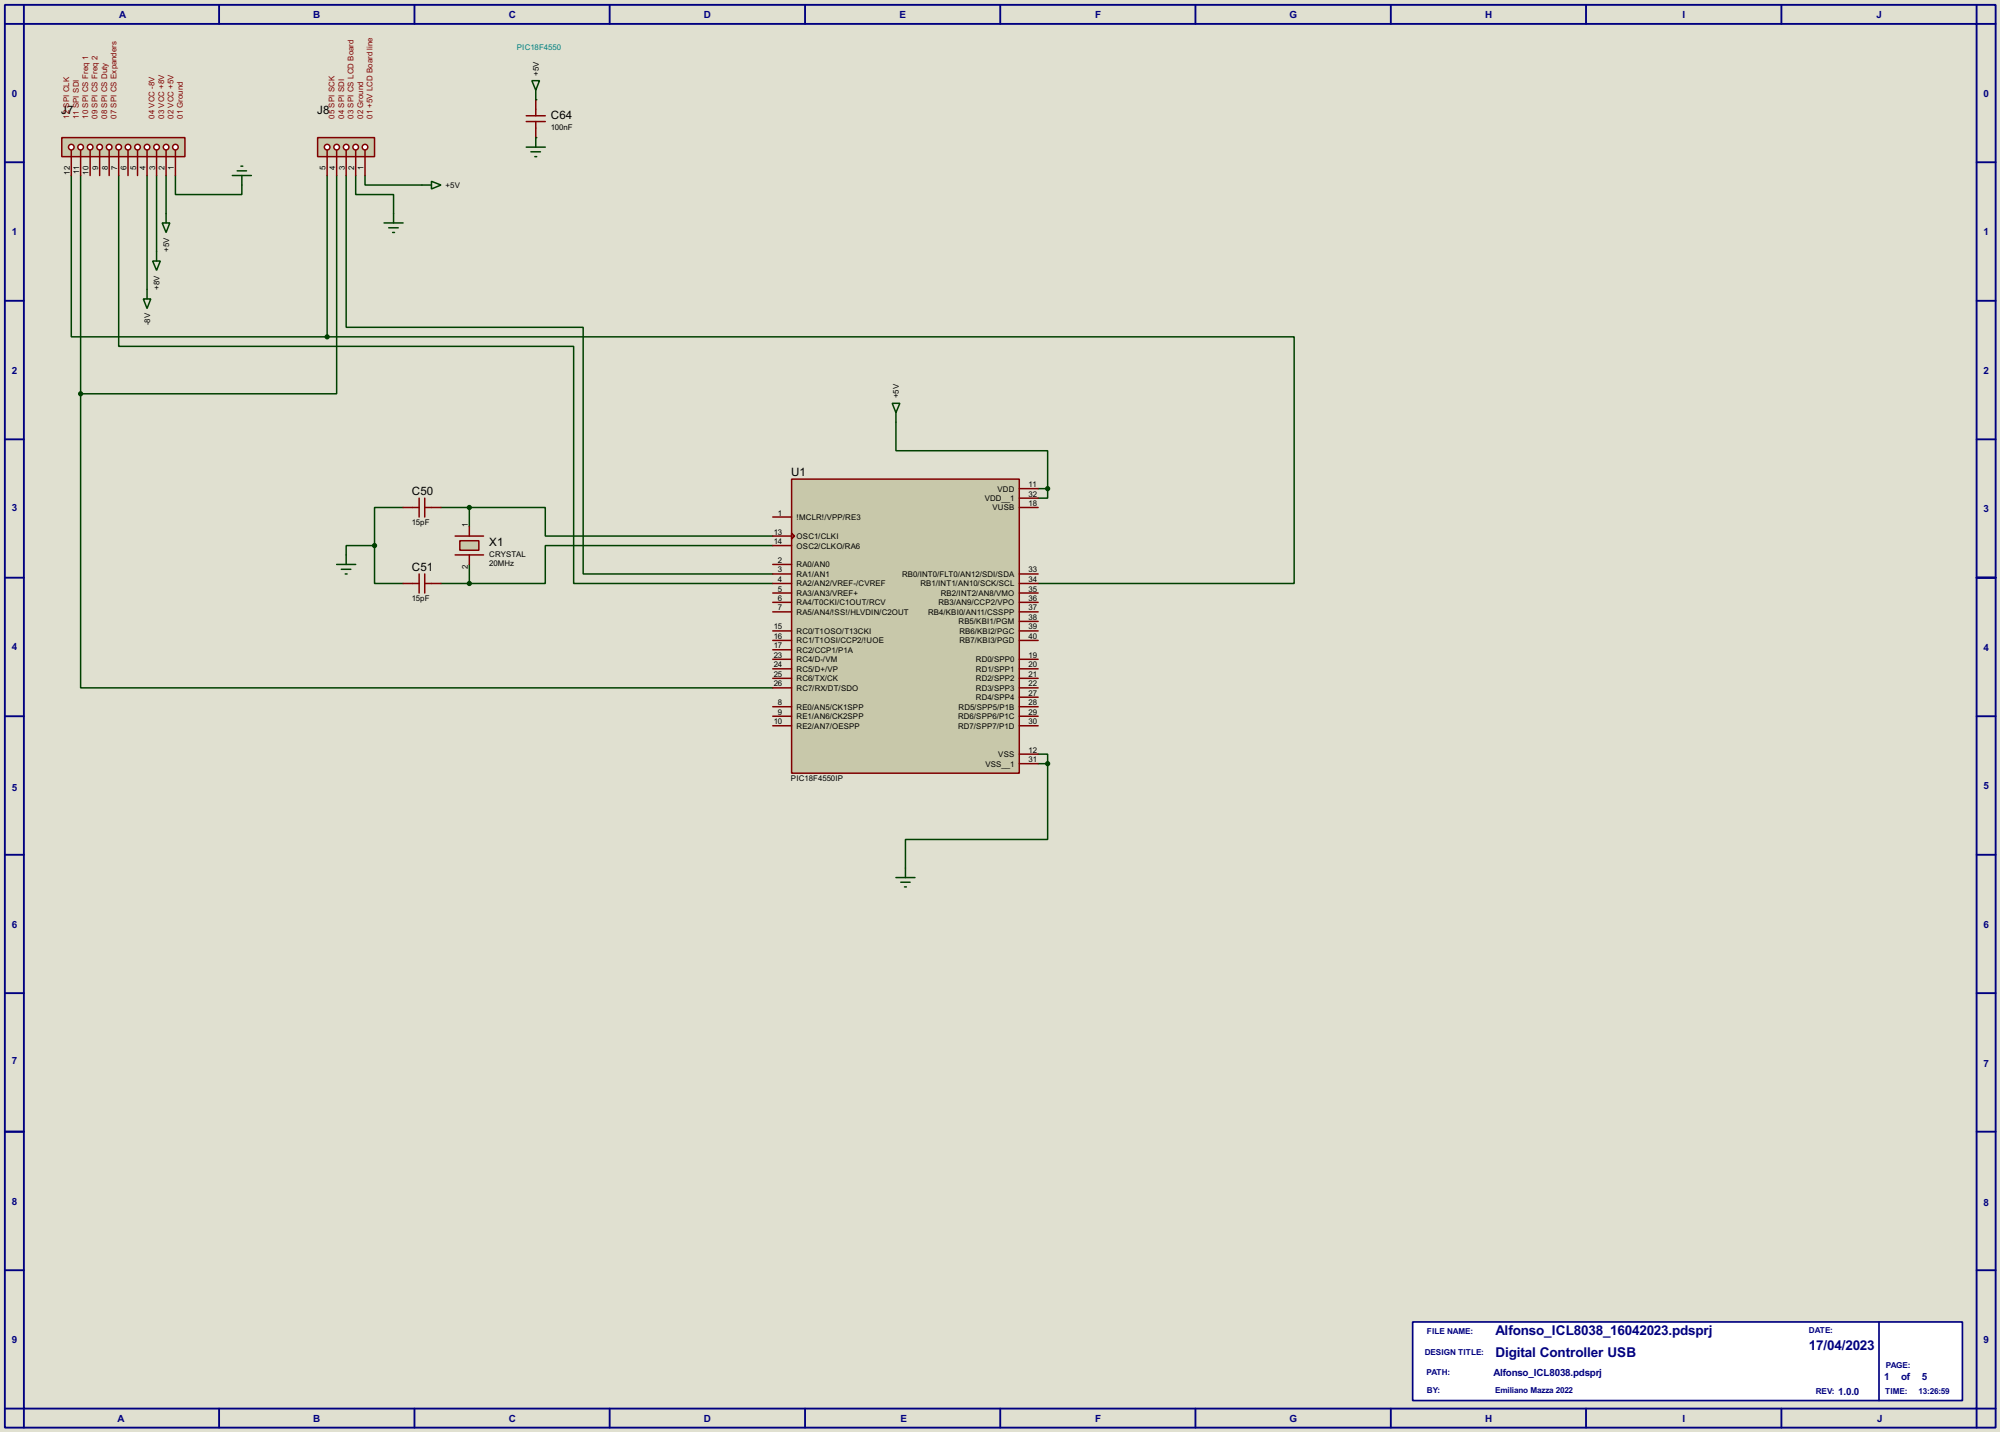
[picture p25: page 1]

08 SPI CS Duty 07 SPI CS Expanders

04 SPI SDI 03 SPI CS LCD Board
J8 05 SPI SCK

11 SPI SDI 10 SPI CS Freq 1

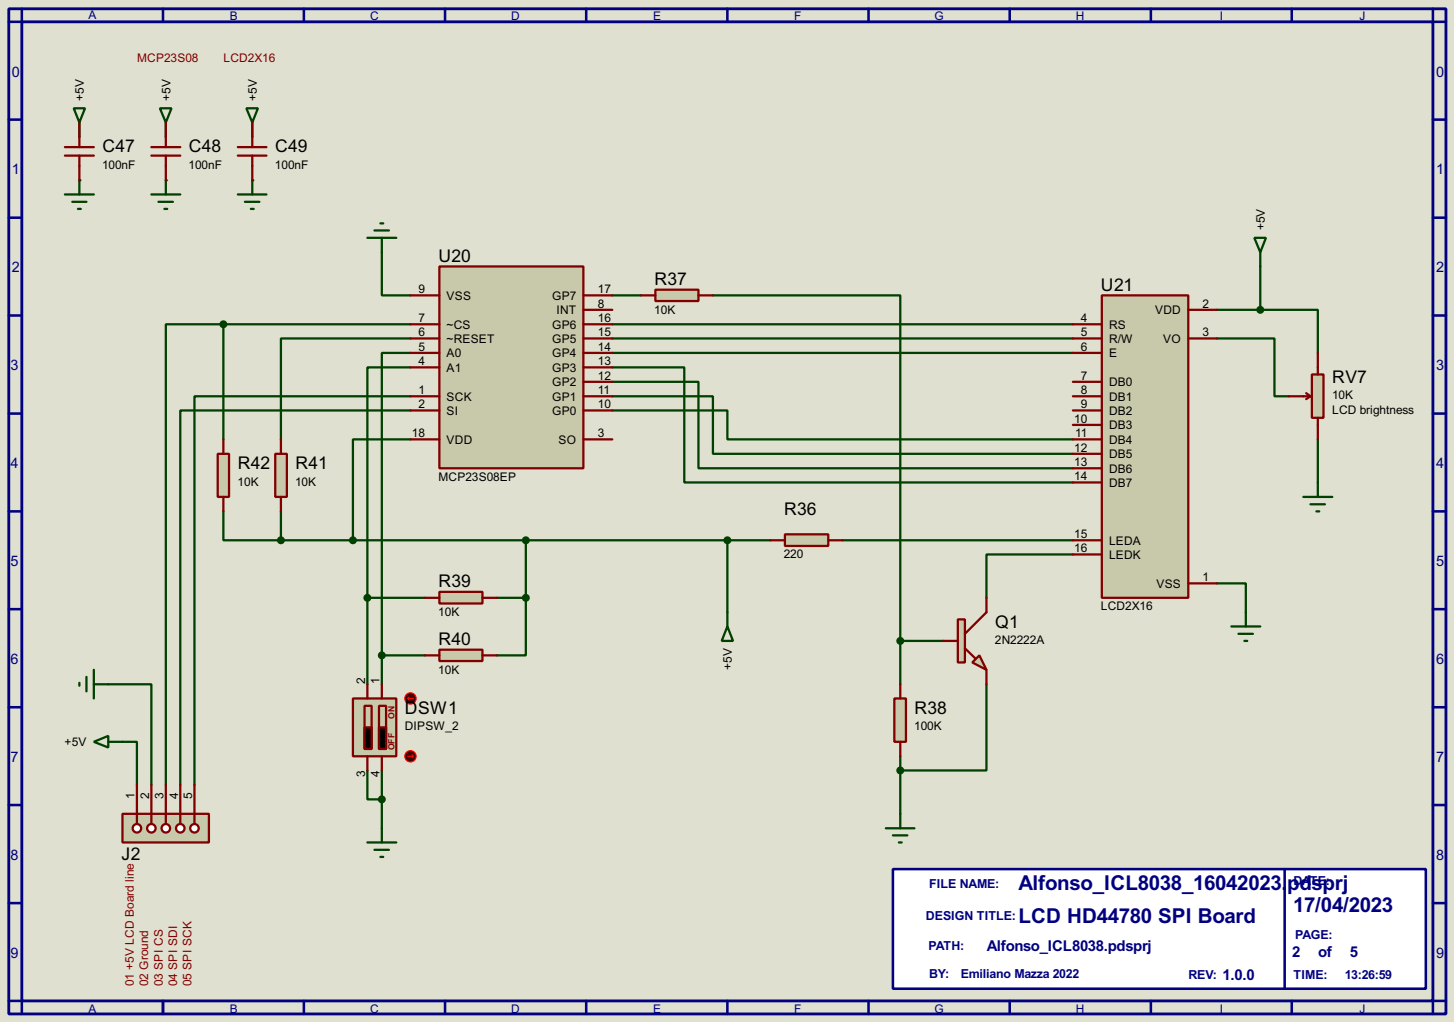
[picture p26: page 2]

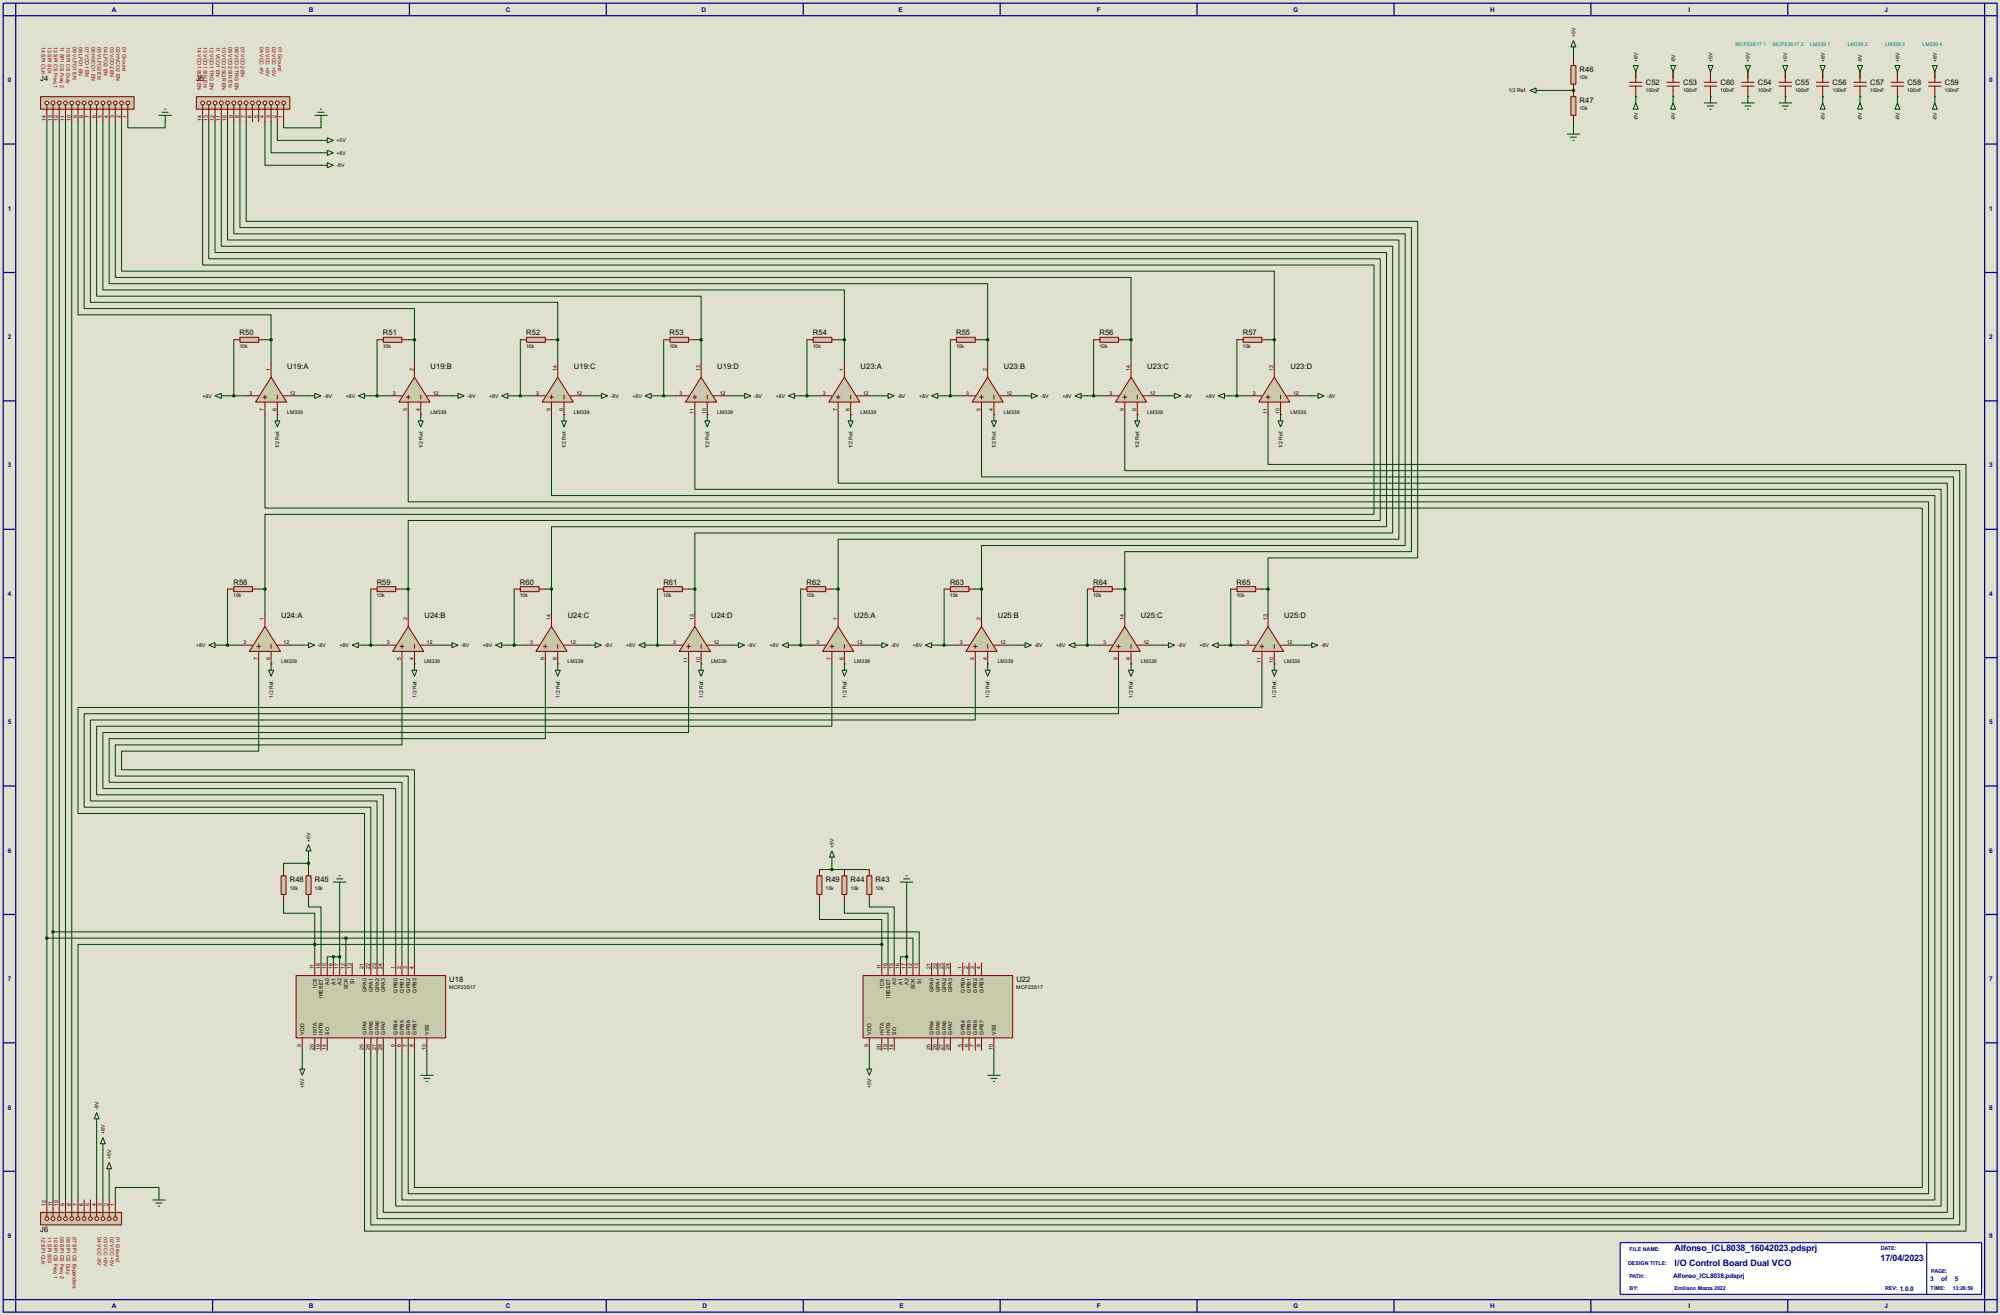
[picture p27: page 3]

13 SPI SDI 12 SPI CS Freq 1

10 SPI CS Duty 09 VLFO1 EN

11 SPI SDI 10 SPI CS Freq 1

08 SPI CS Duty 07 SPI CS Expanders

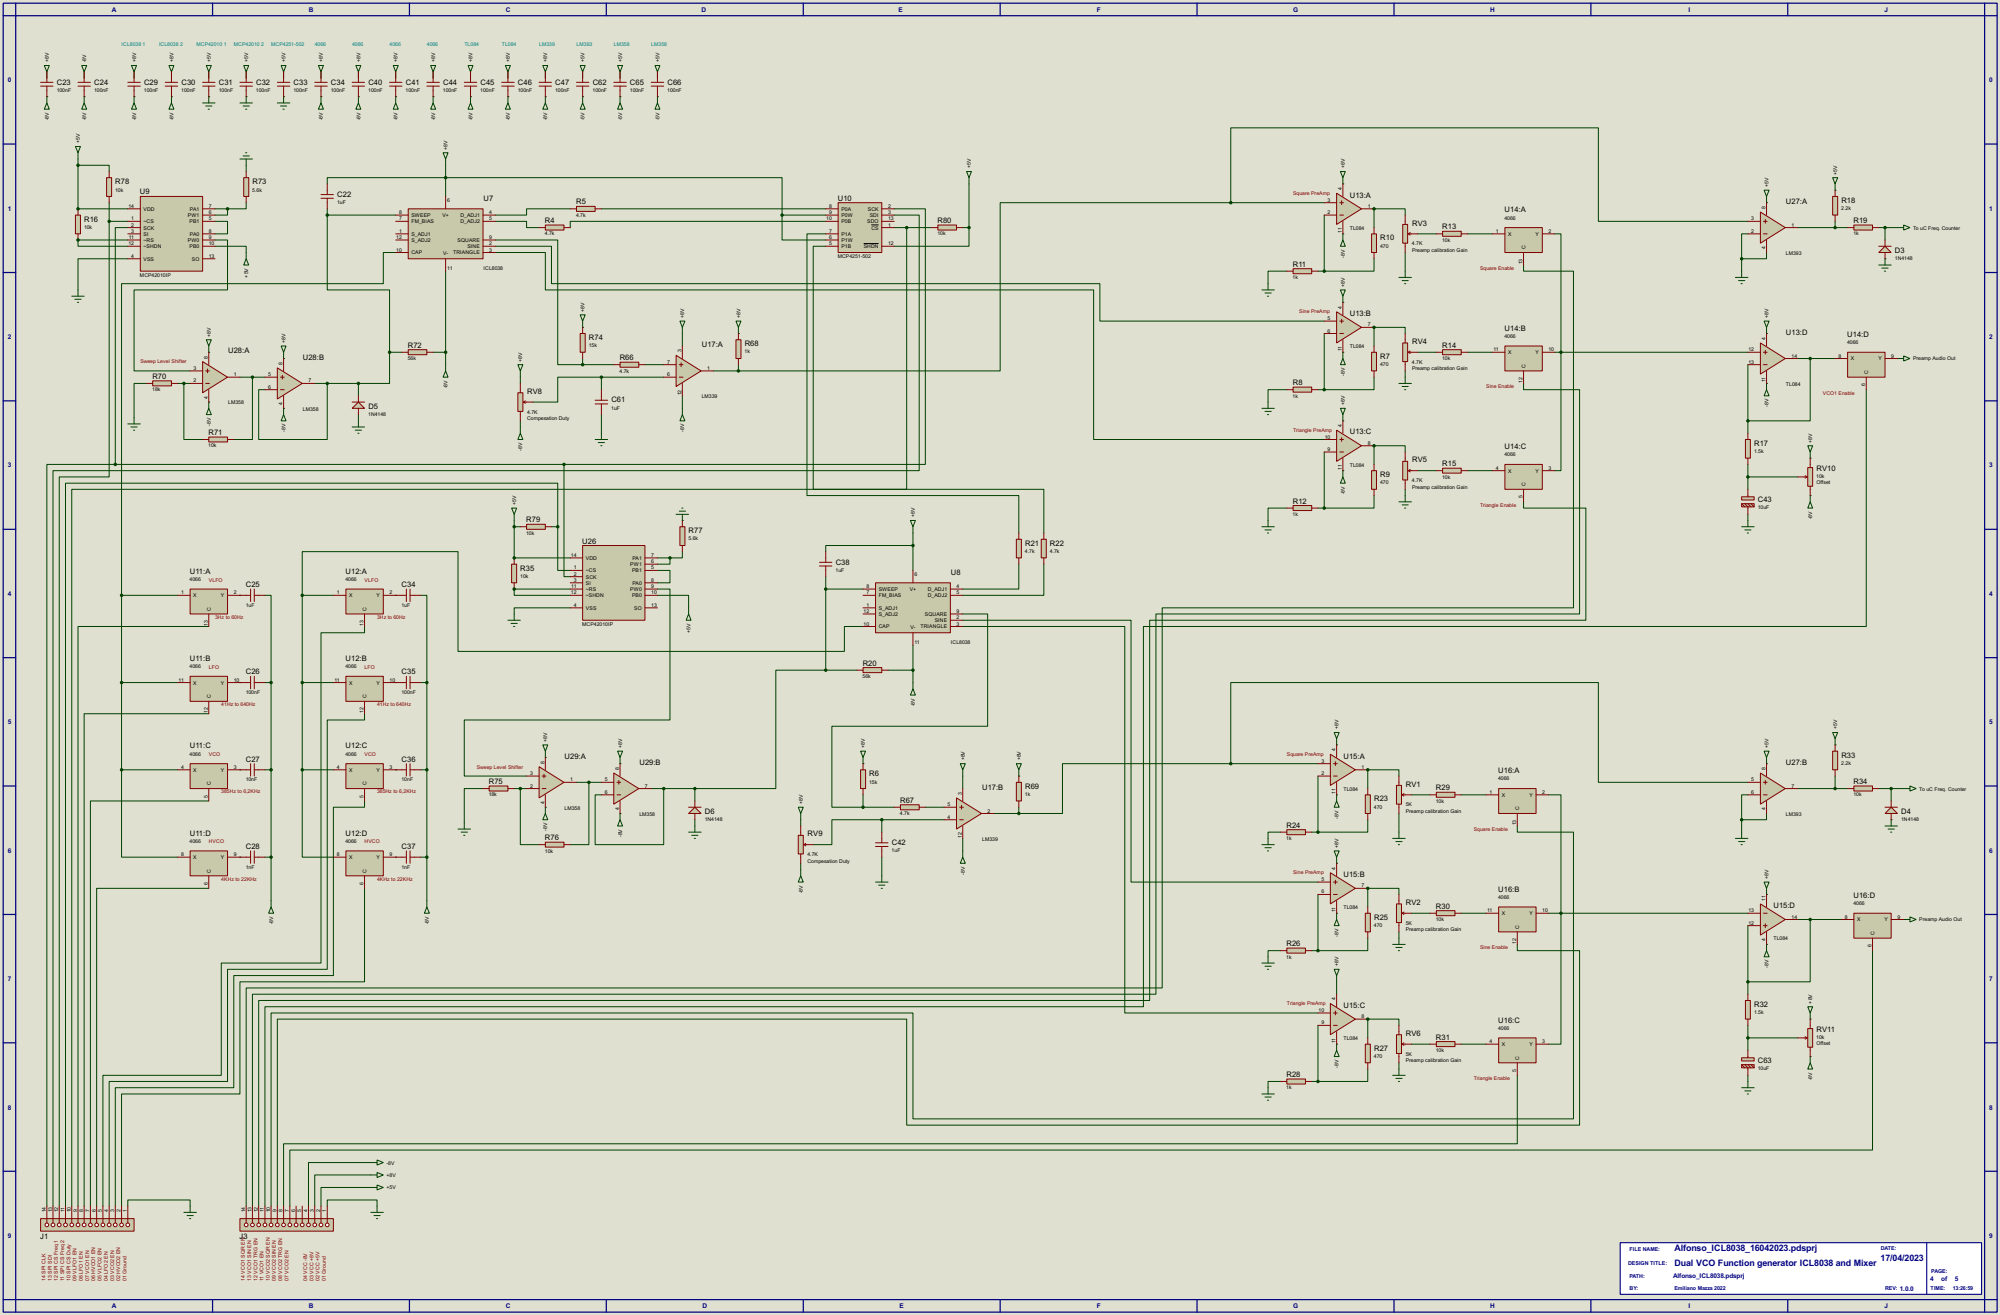
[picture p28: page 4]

8 | P0W P0A | 2 SDI 3 CS

R16 | 1 | PW1 ~CS PB1 | 6 SCK 5 | | 8 7 | FM_BIAS | 4 D_ADJ2 5 V+ | 9 10 | P0B SDO | 13

SCK

To uC Freq. Counter

13 SPI SDI 12 SPI CS Freq 1

10 SPI CS Duty 09 VLFO1 EN

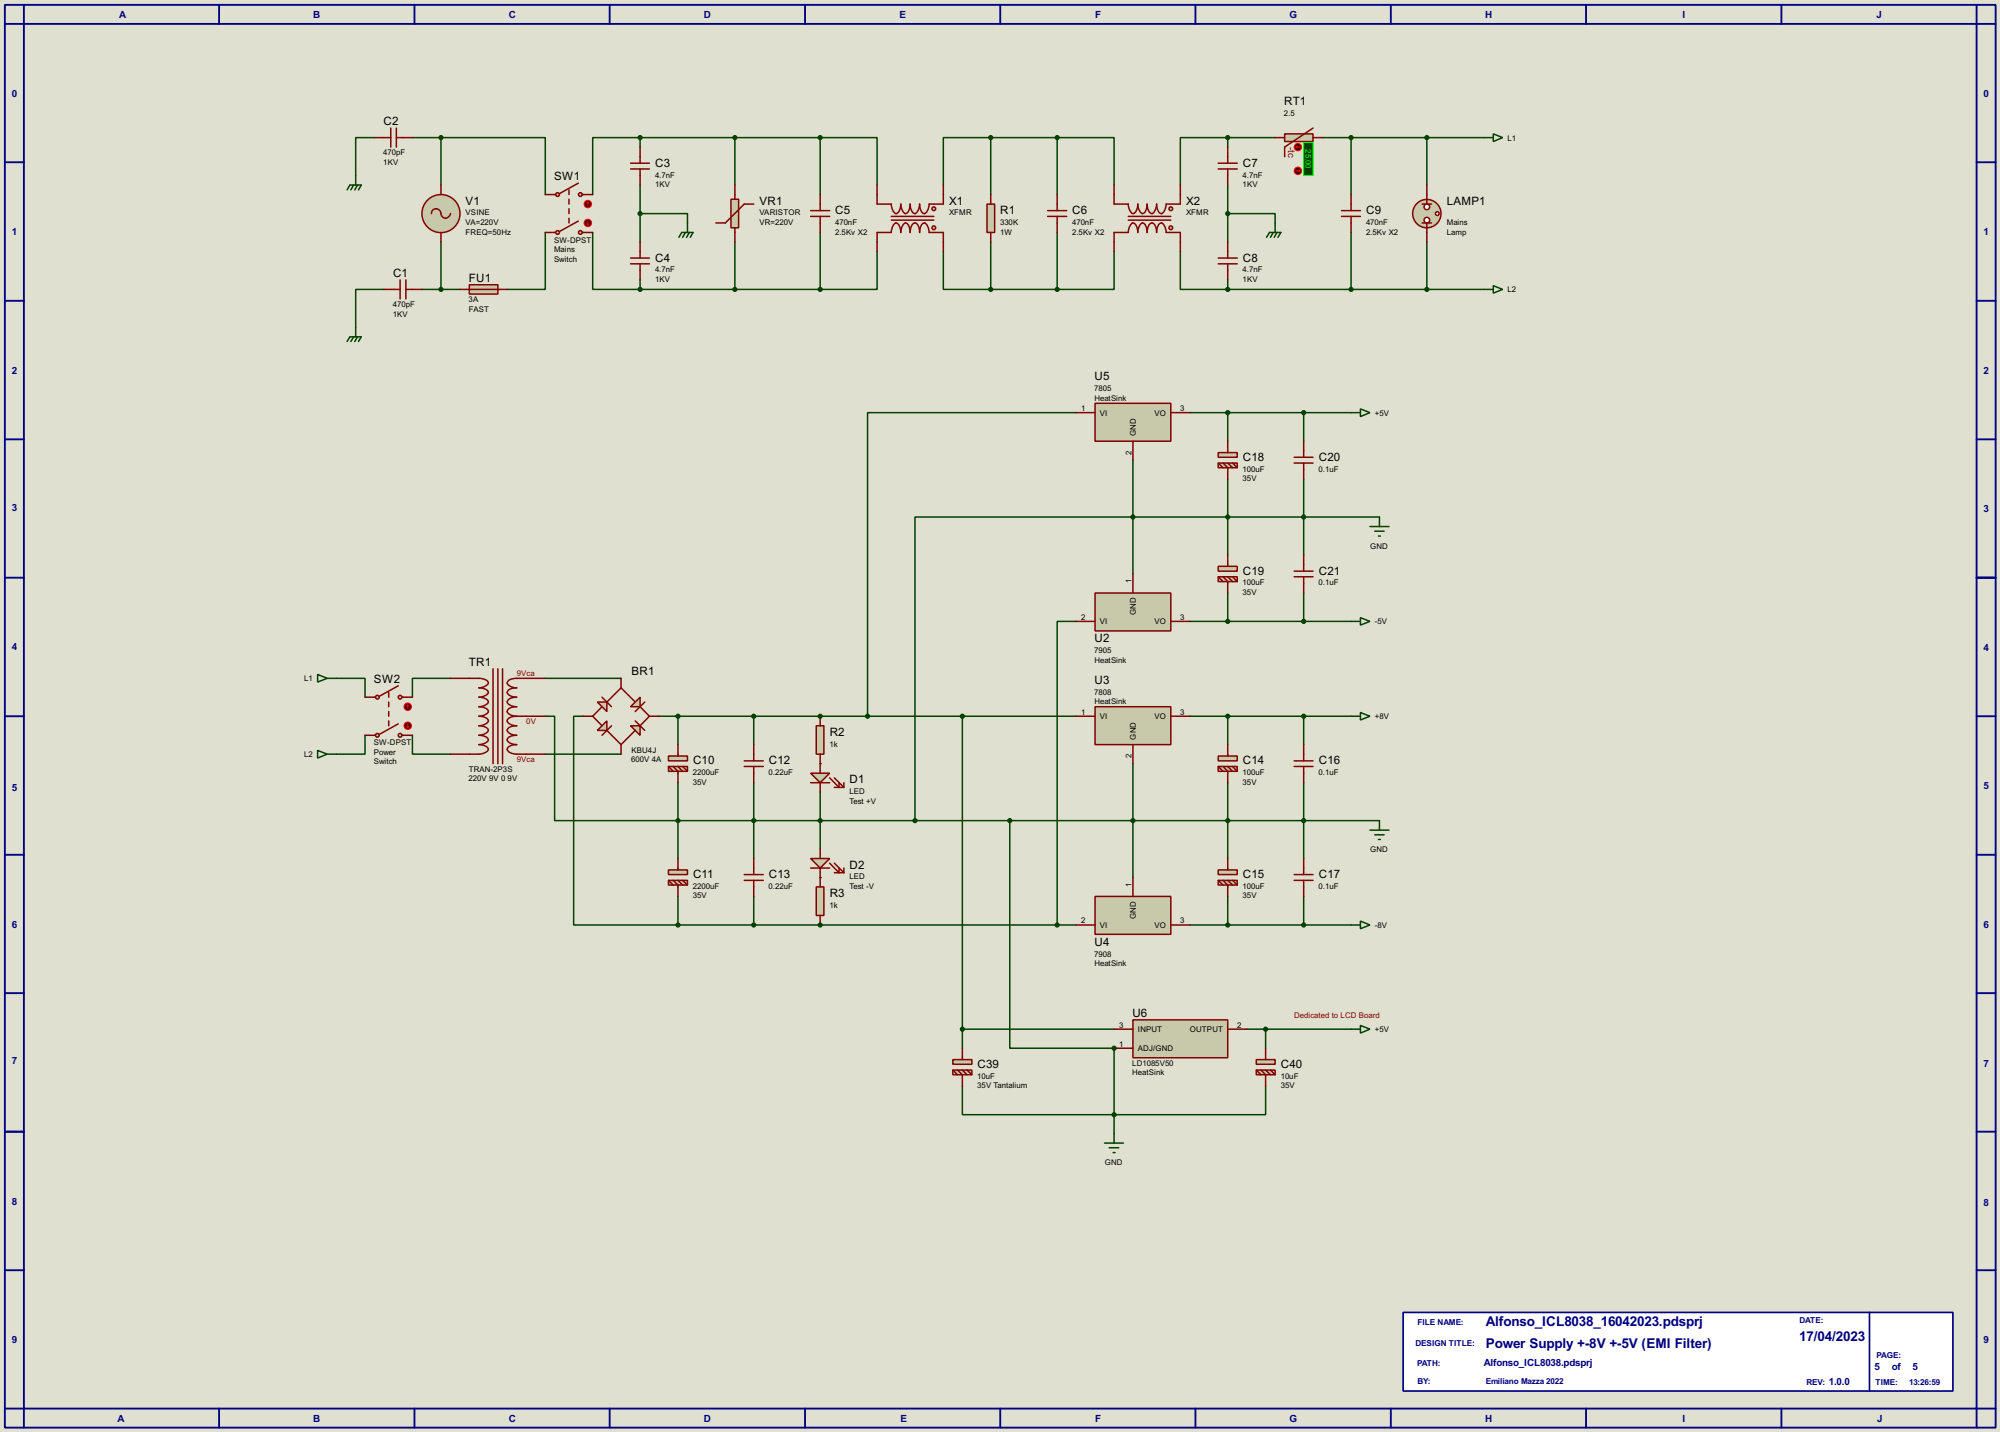
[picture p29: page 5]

SW-DPST Mains Switch

SW-DPST Power Switch

+5V Dedicated to LCD Board

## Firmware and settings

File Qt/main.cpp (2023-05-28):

/*******************************************************************************

 A.L.F.O.N.S.o
 Author : Emiliano Mazza
 Version : 1.0
 Created on Date : 15/18/2020
 Last update     : 31/01/2023

 CopyRight 2006-2015 all rights are reserved

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
*******************************************************************************/

#include <QGuiApplication>
#include <QQmlApplicationEngine>
#include <QQuickView>
#include <QTimer>
#include <QIcon>

#include "main.h"
#include "protocol.h"
#include "serialPortController.h"
#include "mixer.h"
#include "potentiometer.h"
#include "toggleSwitch.h"
#include "tabButton.h"
#include "freqLabel.h"
#include "freqSelector.h"

int main(int argc, char *argv[])
{
    QCoreApplication::setOrganizationName(PROJECT_NAME);

#if QT_VERSION < QT_VERSION_CHECK(6, 0, 0)
    QCoreApplication::setAttribute(Qt::AA_EnableHighDpiScaling);
#endif

    QGuiApplication app(argc, argv);

    // Register singleton for Constants
    qmlRegisterSingletonType(QUrl("qrc:/content/Constants.qml"), "com.alfonso.qml.constants", 1, 0, "Constants");
    // Register singleton for Protocol
    qmlRegisterSingletonType<Protocol>("com.alfonso.protocol", 1, 0, "Protocol", Protocol::qmlInstance);
    // Register singleton for Mixer
    qmlRegisterSingletonType<Mixer>("com.alfonso.mixer", 1, 0, "Mixer", Mixer::qmlInstance);
    // Register controller singleton for the Serial Port
    qmlRegisterSingletonType<SerialPortController>("com.alfonso.serialportcontroller", 1, 0, "SerialPortController", SerialPortController::qmlInstance);

    // Register QML Controls
    qmlRegisterType<TabButton> ("com.alfonso.qml.controls", 1, 0, "TabButton");
    qmlRegisterType<FreqLabel> ("com.alfonso.qml.controls", 1, 0, "FreqLabel");
    qmlRegisterType<FreqSelector> ("com.alfonso.qml.controls", 1, 0, "FreqSelector");
    qmlRegisterType<Potentiometer> ("com.alfonso.qml.controls", 1, 0, "Potentiometer");
    qmlRegisterType<ToggleSwitch> ("com.alfonso.qml.controls", 1, 0, "ToggleSwitch");

    QQmlApplicationEngine engine;
    const QUrl url(u"qrc:/main.qml"_qs);
    QObject::connect(
                &engine, &QQmlApplicationEngine::objectCreated, &app,
                [url](QObject *obj, const QUrl &objUrl) {
        if (!obj && url == objUrl)
            QCoreApplication::exit(-1);
    },
    Qt::QueuedConnection);

    // Adds resource path
    engine.addImportPath(QCoreApplication::applicationDirPath() + "/content");
    engine.addImportPath(":/");

    engine.load(url);

    if (engine.rootObjects().isEmpty()) {
        return -1;
    }

    // Get instance in C++ of SerialPortController
    SerialPortController* oSerialPortController = SerialPortController::getInstance();
    // Get instance in C++ of Mixer
    Mixer* oMixer = Mixer::getInstance();

    // Find MainWindow
    QObject* oMainWindowObj = engine.rootObjects().first();

    // Find SplashWindow
    QObject* oSplashWinObj = engine.rootObjects().first()->findChild<QObject*>("SplashWindowObject");

    // Connect main window catch the quit for USB Serial control
    QMetaObject::Connection oConnMainWindowSerCtrl = QObject::connect(oMainWindowObj, SIGNAL(underClosingALFONSo()), oSerialPortController, SLOT(requestALFONSoUnderClosing()));
    // Connect main window catch the quit for Mixer
    QMetaObject::Connection oConnMainWindowMixer = QObject::connect(oMainWindowObj, SIGNAL(underClosingALFONSo()), oMixer, SLOT(requestALFONSoUnderClosing()));
    // Connect ALFONSo USB Serial control for search ALFONSo HW
    QMetaObject::Connection oConnSplashWinObj = QObject::connect(oSplashWinObj, SIGNAL(isALFONSoUSBPresent()), oSerialPortController, SLOT(requestIsALFONSoUSBPresent()));

    // Signal emitted at startup implementation
    //QTimer::singleShot(2000, [=]() { QObject::disconnect(oConnection); } );

    return app.exec();
}

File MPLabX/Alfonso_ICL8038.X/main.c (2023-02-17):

/*******************************************************************************

Author : Emiliano Mazza
Version : 1.0
Created on Date : 15/18/2020
Last update     : 31/01/2023

CopyRight 2006-2015 all rights are reserved

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
This module contains main startup function and the startup always loop

*******************************************************************************/

#include <xc.h>
#include "globals.h"
#include "system.h"

/*
 * 
 */
int main (void) {

    // Startup the main setup configuration
    ConfigSystemState(SYSTEM_STATE_START_INIT);
    
    // TO DO !!!
    // Wait for one second
    __delay_ms(1000);
    // TO DO !!!
    
    // Initializes the USB device stack it in the default state.
    USBDeviceInit();
    // Checks if VBUS is present, and that the USB module is not already
    // initialized, and if so, enables the USB module so as to signal device
    // attachment to the USB host.
    USBDeviceAttach();
    
    // Startup completed
    ConfigSystemState(SYSTEM_STATE_COMPLETED_INIT);
    
	// Infinite loop
	while (1) {
        
        #if defined(USB_POLLING)
            // Interrupt or polling method.  If using polling, must call
            // this function periodically.  This function will take care
            // of processing and responding to SETUP transactions
            // (such as during the enumeration process when you first
            // plug in).  USB hosts require that USB devices should accept
            // and process SETUP packets in a timely fashion.  Therefore,
            // when using polling, this function should be called
            // regularly (such as once every 1.8ms or faster** [see
            // inline code comments in usb_device.c for explanation when
            // "or faster" applies])  In most cases, the USBDeviceTasks()
            // function does not take very long to execute (ex: <100
            // instruction cycles) before it returns.
            USBDeviceTasks();
        #endif

        //Exec main task
        MainSystemTasks();
 	}

}

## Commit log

2023-01-17 I2C Library
2023-01-17 I2C I/O Expander PCF8574 Library
2023-01-17 SPI Library
2023-01-17 SPI MCP42XXX Digital Potentiomenters Library
2023-01-17 SPI MCP425X Digital Potentiomenters Library
2023-01-17 SPI I/O Expander MCP23S08 Library
2023-01-17 LCD 44780 interfaced SPI I/O Expander MCP23S08 Library
2023-01-17 Fuses and defines main definitions
2023-01-17 Wiring diagram in PDF Format
2023-02-07 MCP42010 Schema part for Proteus.
    [MCP42010-I_P.step]
2023-02-08 Schema update.
    [LCD2X16.step]
2023-02-09 Schema update
    [MCP23S08-E_P.step, PIC18F4550-I_P.step]
2023-03-14 Continus schema fixing and updating.
    [CD4066BE.step, LM339N.step]
2023-04-11 Schema parts.
    [SMD-DIODE-SCHOTTKY-40V-1A_DO-214AC_.step]
2023-04-17 Schema al last update using +8/-8V. Last at 16/04/2023.
2023-04-17 Updating schema to new power supply configuration +5/-5V.
2023-04-19 Fix Duty Cycle CS port
    [system.c, system.h]
2023-04-19 Fitting to +5V/-5V
2023-06-19 Added support for USART debugging with printf.
2023-06-19 Fix I2C functions, unused with this project.
    [I2CLib.c, PCF8574.c]
2023-06-22 Added command for request current VCO frequency.
2023-06-22 Added button for request current VCO frequency.
